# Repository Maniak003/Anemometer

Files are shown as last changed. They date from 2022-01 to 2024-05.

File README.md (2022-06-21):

<!DOCTYPE html>
<html lang="en" data-color-mode="auto" data-light-theme="light" data-dark-theme="dark">
  <head>
    <meta charset="utf-8">
  </head>
    <body class="logged-in env-production page-responsive page-blob" style="word-wrap: break-word;">
      <p> UltraSonic Anemometer.<br><b>Temperature instability was found. I'm trying to solve a problem. </p>
      <a href="https://github.com/Maniak003/Anemometer/wiki" rel="nofollow">
        Wind watcher
      </a>
      <a href="https://github.com/Maniak003/Anemometer/wiki/ZabbixSetting" rel="nofollow">
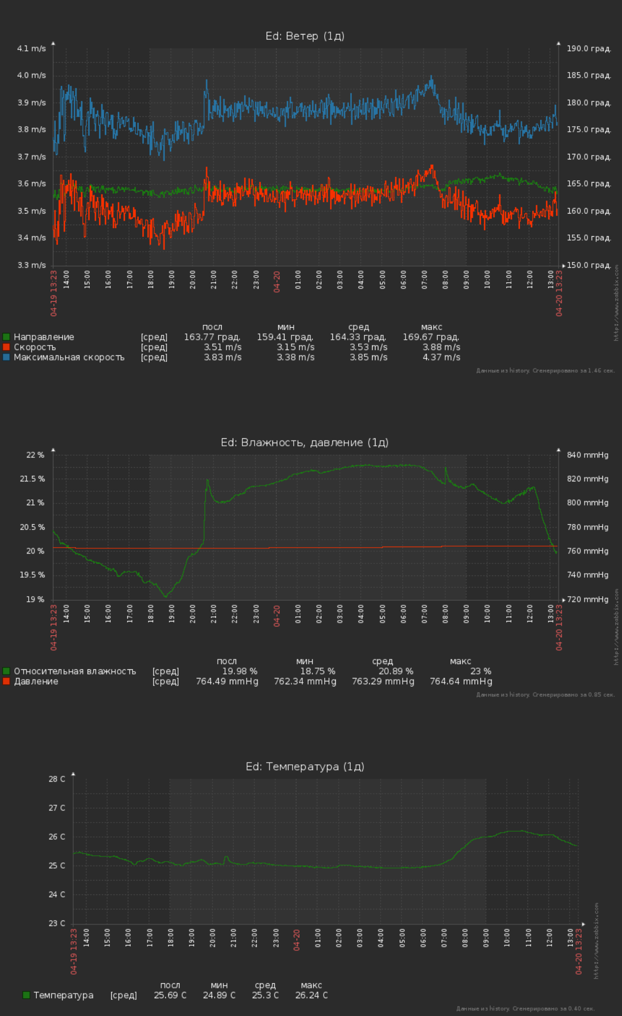
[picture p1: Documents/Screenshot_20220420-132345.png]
        
      </a>
      <a href="https://github.com/Maniak003/Anemometer/wiki/Description" rel="nofollow">
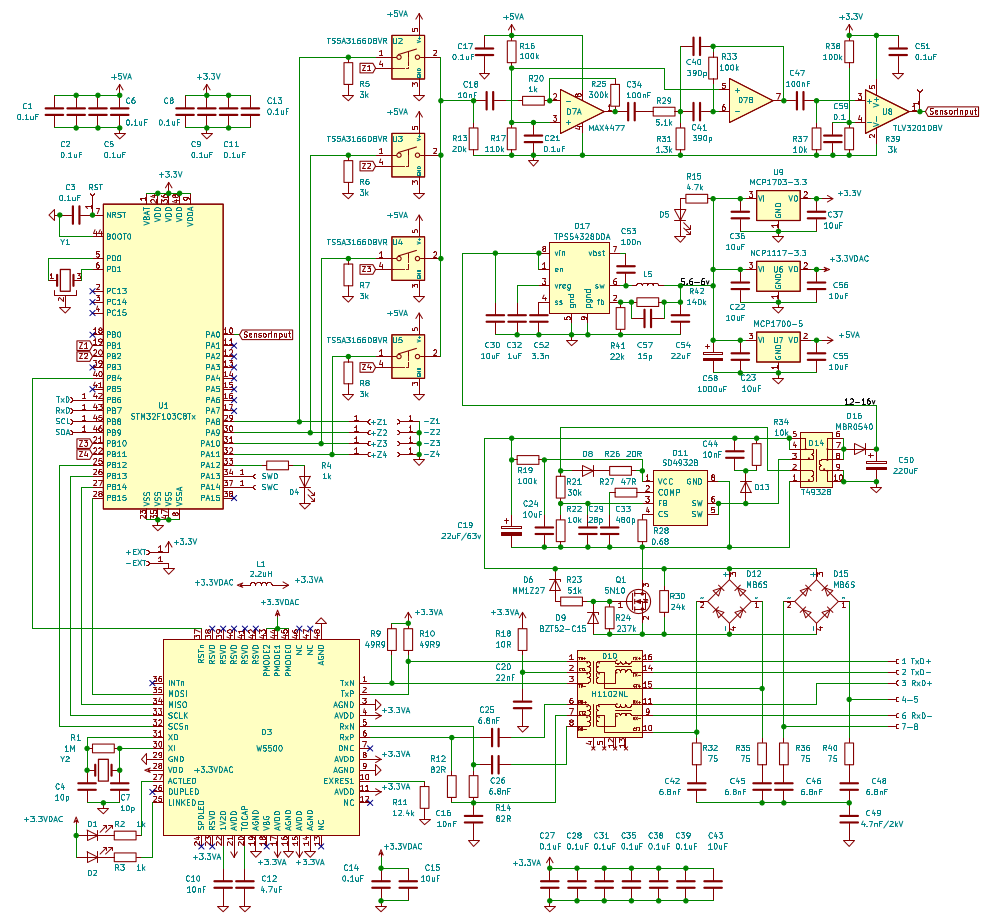
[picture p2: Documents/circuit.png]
        
      </a>
      <a href="https://github.com/Maniak003/Anemometer/wiki/Description" rel="nofollow">Description</a>
    </body>
</html>

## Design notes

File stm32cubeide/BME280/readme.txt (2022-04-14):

1. Запустим с помощью Cube MX файл в корне папки с проектом с расширением ioc
2. В Cube MX сгенерируем проект и откроем его.
3. Скомпилируем проект в Keil и проектом теперь можно пользоваться.

1. Start by using Cube MX file in the root folder with the project with the extension ioc
2. Generate the project in the Cube MX and open it.
3. Compile the project in the Keil and the project can now be used.

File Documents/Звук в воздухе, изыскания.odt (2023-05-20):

Скорость звука.

v = sqrt{ dP over {d%rho }}; v= sqrt{ %chi *{{R * T} over %mu} } (1)

χ – Показатель адиабаты. Отношение теплоемкостей при постоянном давлении и постоянном объеме.

R – Универсальная газовая постоянная.

T – Температура в градусах Кельвина.

μ – Молярная масса.

Парциальное давление насыщенного пара, эмпирическая формула, от -45ºC до 45ºC .

P_н = 1.84 * 10^11 * e^ left( - {{5330} over {T}} right ) (2)

Расчет парциального давления по относительной влажности.

P_п = { f_1 } over { 100 } * P_н (3)

Влажный воздух — смесь водяного пара и сухого воздуха. Давление влажного воздуха равно сумме парциальных давлений сухого воздуха и водяного пара. Молярная масса влажного воздуха.

%mu = r_в*%mu_в + r_п*%mu_п (4)

rв - Объемная доля сухого воздуха.

rп - Объемная доля водяного пара.

r_в = P_в over P = { (P - P_п) } over P (5); r_п = P_п over P (6)

%mu = 28.98 - 10.944 * {{ P_п } over P} (7)

Молярная масса водяного пара.

Состав воздуха.

O_2^{21%} + N_2^{ 78% } + Ar_2^{ 0.5%} + CO_2^{ 0.5% } (8)

Состав воды.

H_2^2 + O^1
(9)

Молярная масса через количество вещества.

%mu_{ cp } =( sum from{1} to{n} M_i*v_i ) / ( sum from{1} to{n} v_i ) (10)

%mu_{ cp }(воздуха) = {( 0.21 * 32 + 0.78 * 28 + 0.005 * 40 + 0.005 * 44 )} over { 0.21 + 0.78 + 0.005 + 0.005 } = 28.98 г over моль (11)

%mu_{ cp }(воды) = {( 2 * 1.0 + 1 * 16)} over 1000 = 18 г over моль (12)

Проверка влияния влажности на скорость звука.

Пусть температура постоянная и равна 20º C или 293K. Рассчитаем скорость для сухого воздуха.

v = sqrt{ 1.4 * 8.31446262 * 293 over 0.02898 } = 343,05656 m over s

Теперь рассчитаем скорость звука при той же температуре, но 100% влажности. Сначала получим молярную массу влажного воздуха, для этого нам требуется парциальное давление.

P_н = 1.84*10^11 * e^{ left(-{5330 over 293} right )} = 2314,792465 Па

Рассчитывать будем для нормального атмосферного давления.

%mu = 28.98 - 10.944 * {2314.792465 over 101325} = 28,72998 г over моль

Наконец получим скорость.

v = sqrt{ 1.4 * 8.31446262 * 293 over 0.02872998 } = 344,546 m over s

При изменении влажность на 100%, получаем изменение скорости на 1,489 m/s.

В табличку можно вносить значения: температуры, влажности, давления, времени задержки. Будут рассчитаны: скорость и дистанция.

V = sqrt(1,4*8,31446262*(temperature+273) / (0,02898 - 184000000000 * exp(-5330/(temperature+273)) * 10,944 / (pressure*101325/760) / 100000 * humidity) )

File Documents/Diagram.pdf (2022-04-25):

Z1 | Z2
Z4 | Z3
Z41 | Z14

Z12

Z21

Z32 Z23

Z34

Z43

X = (Z12 - Z21 - DX1.f + Z43 - Z34 - DX2.f) / 2; Y = (Z23 - Z32 - DY2.f + Z14 - Z41 - DY1.f) / 2;

Ю | С

З

В

Zmn

Znm

Pulse | C

# Echo

0º

90º

180º

270º

α = acos( Vx / V)

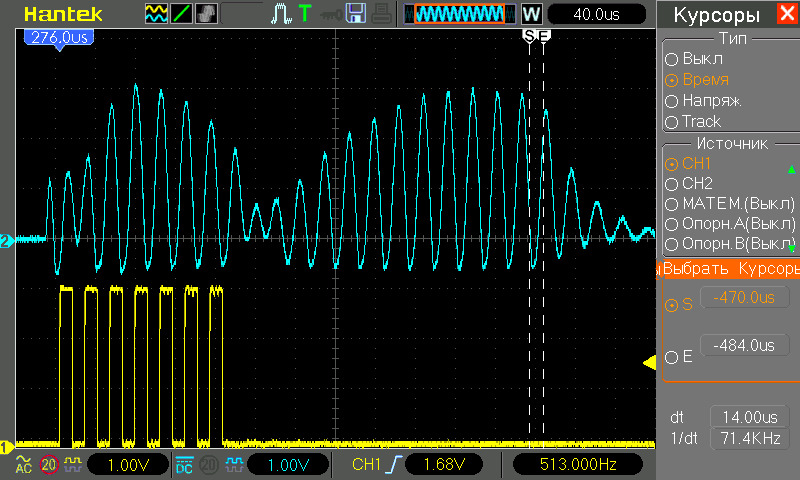
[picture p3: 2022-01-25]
Documents/pic_126_5.jpg

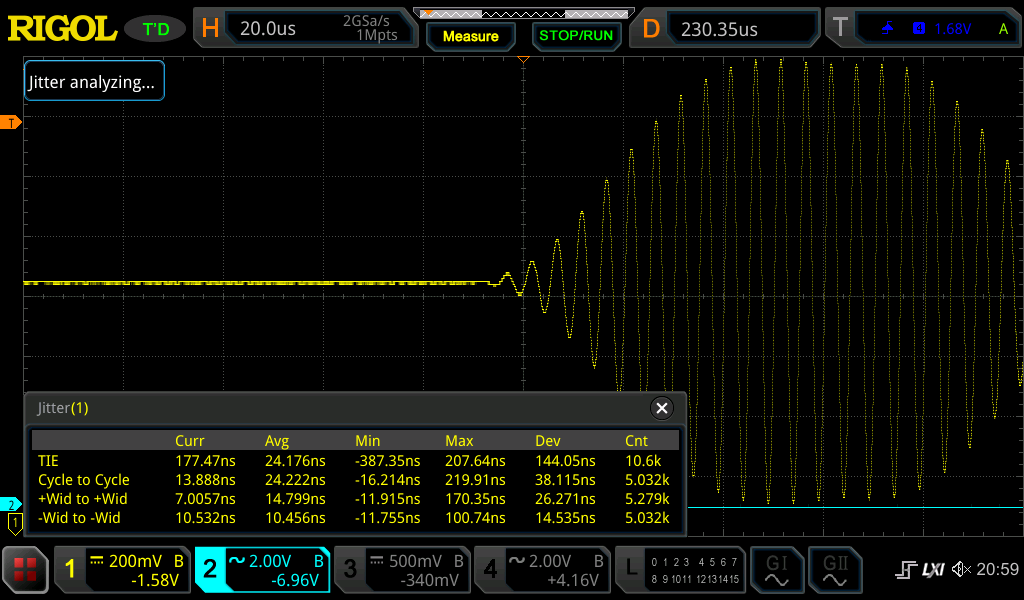
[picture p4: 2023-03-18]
Documents/Jitter-Crystall_200khz.png

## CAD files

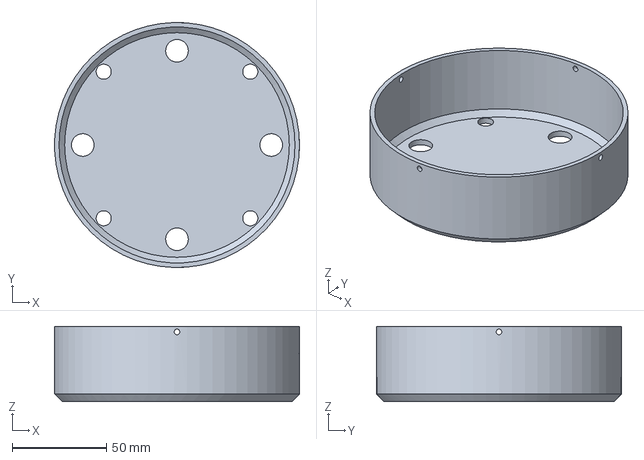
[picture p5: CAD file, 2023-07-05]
FreeCAD/base-200.FCStd
130.0 x 130.0 x 40.0 mm

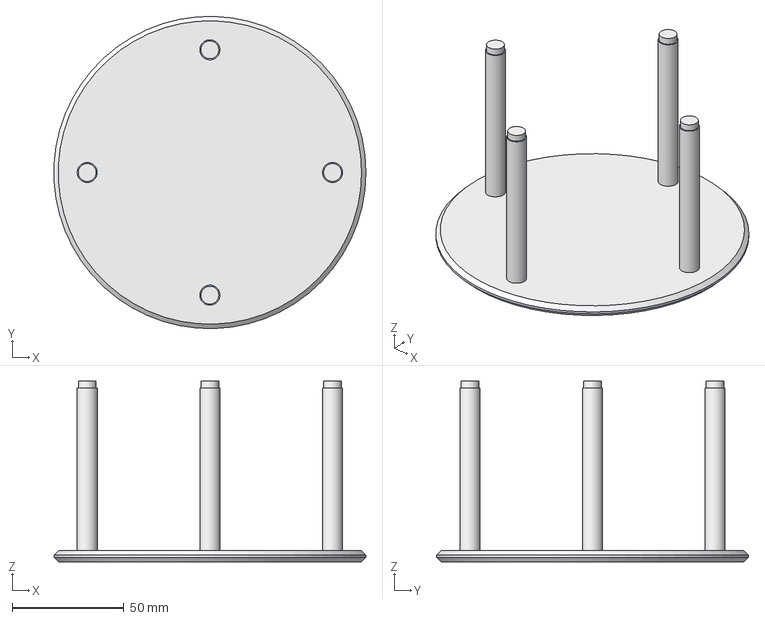
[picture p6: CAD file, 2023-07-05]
FreeCAD/cover-200.FCStd
139.9 x 139.9 x 81.0 mm

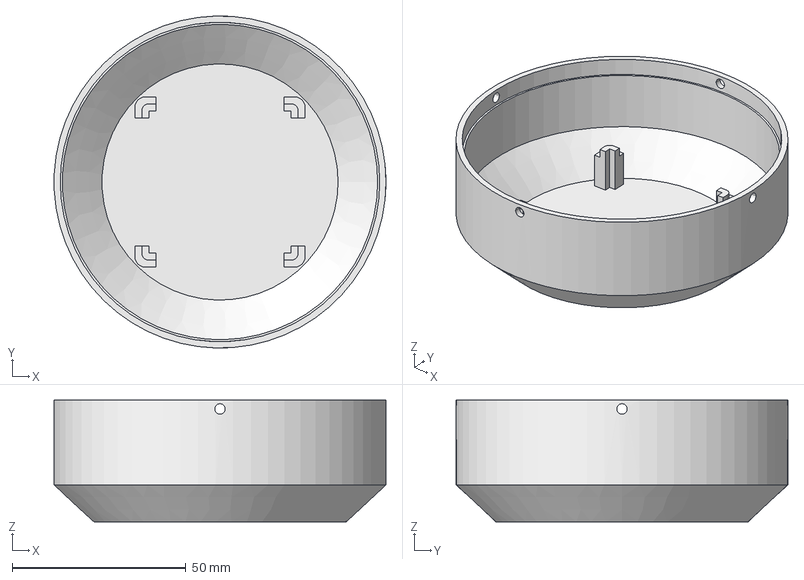
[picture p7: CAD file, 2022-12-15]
FreeCAD/cover-5.FCStd
95.6 x 95.6 x 35.0 mm

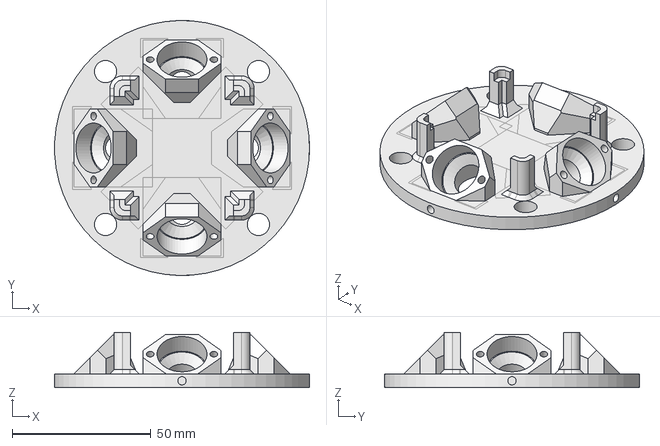
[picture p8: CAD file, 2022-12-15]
FreeCAD/base-5.FCStd
92.0 x 92.0 x 20.0 mm

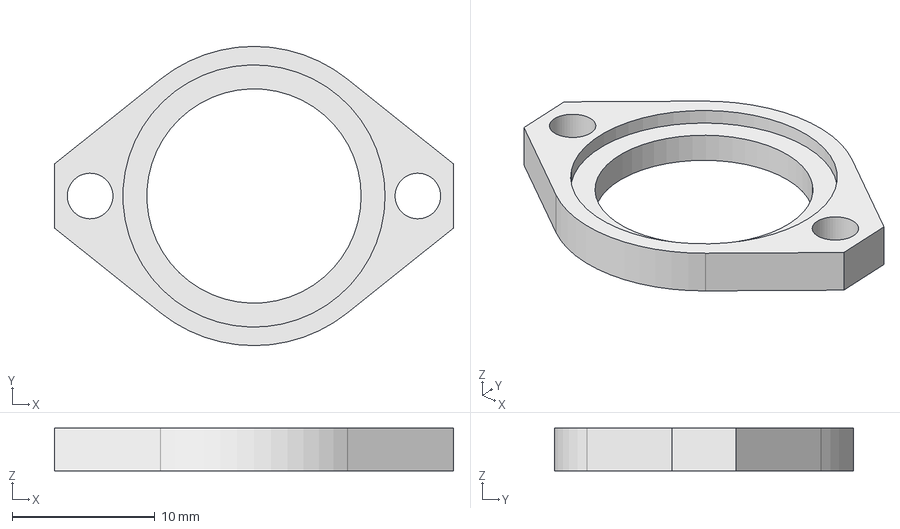
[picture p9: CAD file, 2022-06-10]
FreeCAD/support.FCStd
28.0 x 21.0 x 3.00 mm

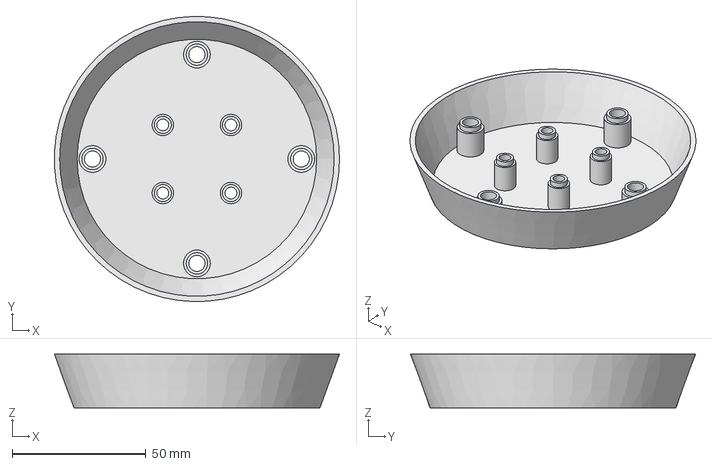
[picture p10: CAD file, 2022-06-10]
FreeCAD/shield-5-1.FCStd
106.5 x 106.5 x 20.0 mm

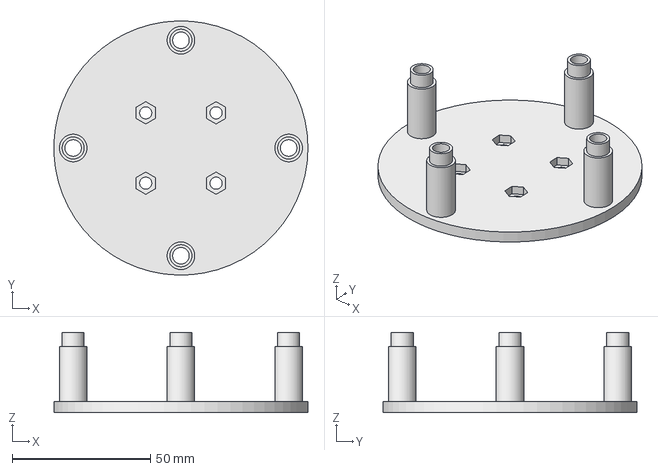
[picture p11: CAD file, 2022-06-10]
FreeCAD/holder-5.fcstd
91.9 x 92.0 x 29.0 mm

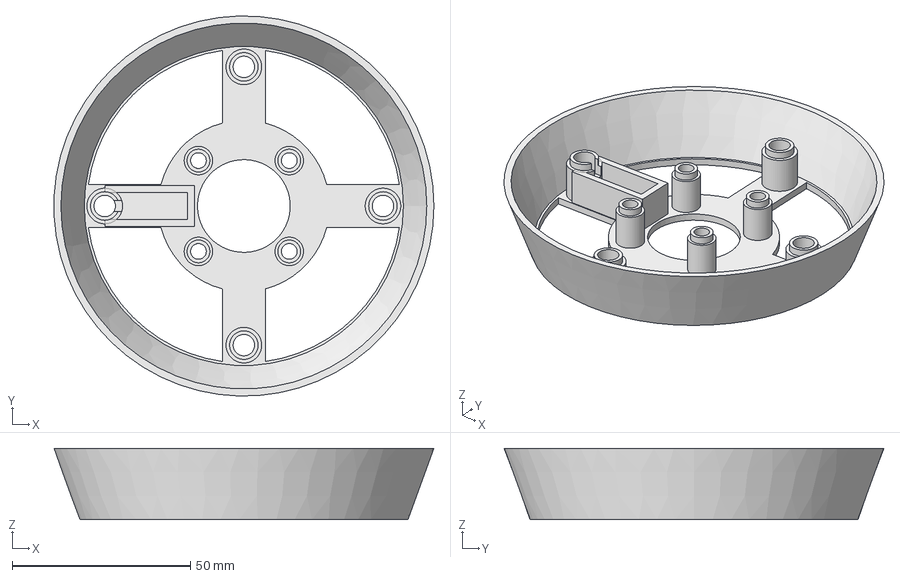
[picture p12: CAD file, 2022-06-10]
FreeCAD/shield-5-2.FCStd
106.5 x 106.5 x 20.0 mm

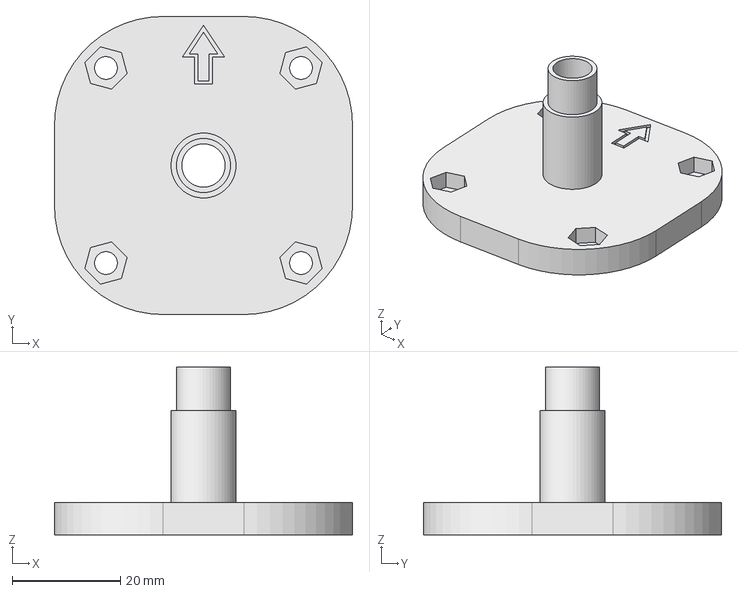
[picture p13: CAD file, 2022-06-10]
FreeCAD/holder-3.fcstd
55.0 x 55.0 x 31.0 mm

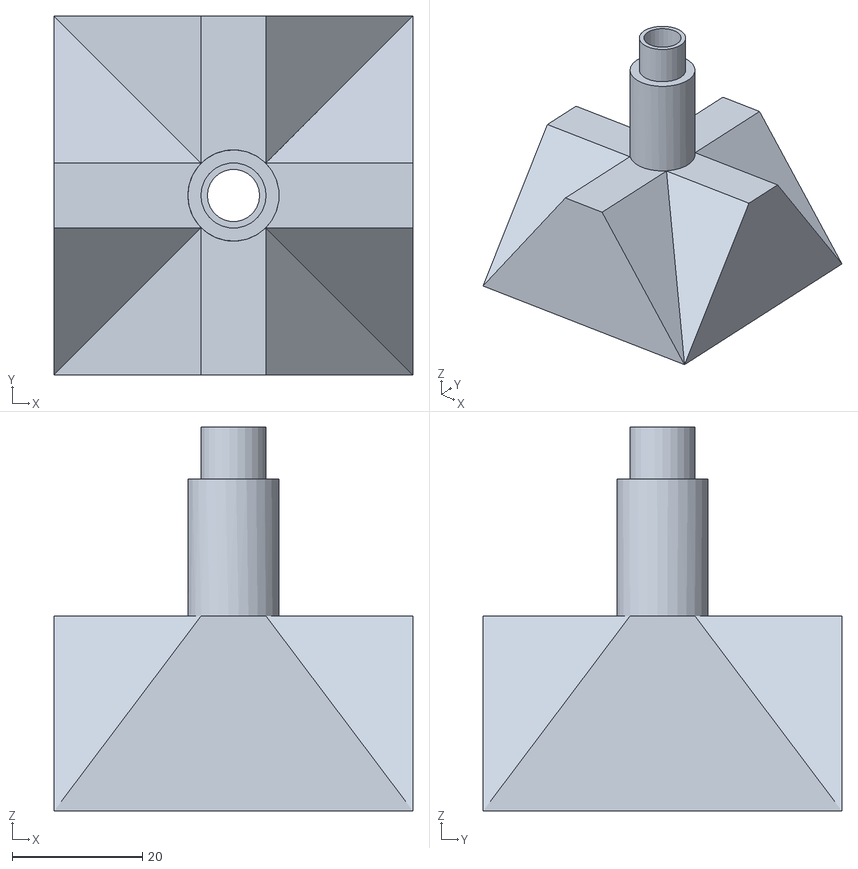
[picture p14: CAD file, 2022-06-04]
FreeCAD/holder-4.stl
55.0 x 55.0 x 58.9

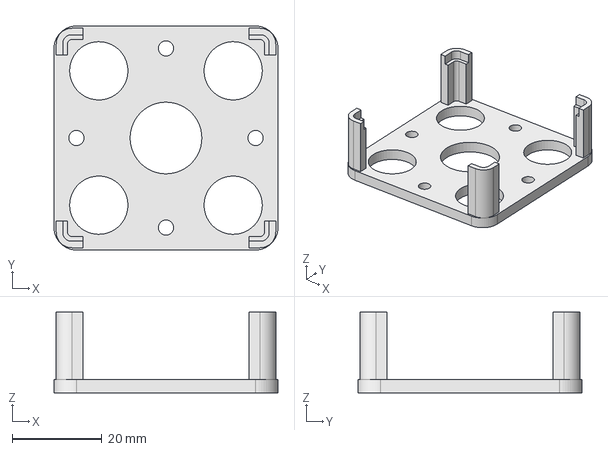
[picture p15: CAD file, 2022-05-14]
FreeCAD/plate-4.FCStd
50.0 x 50.0 x 18.0 mm

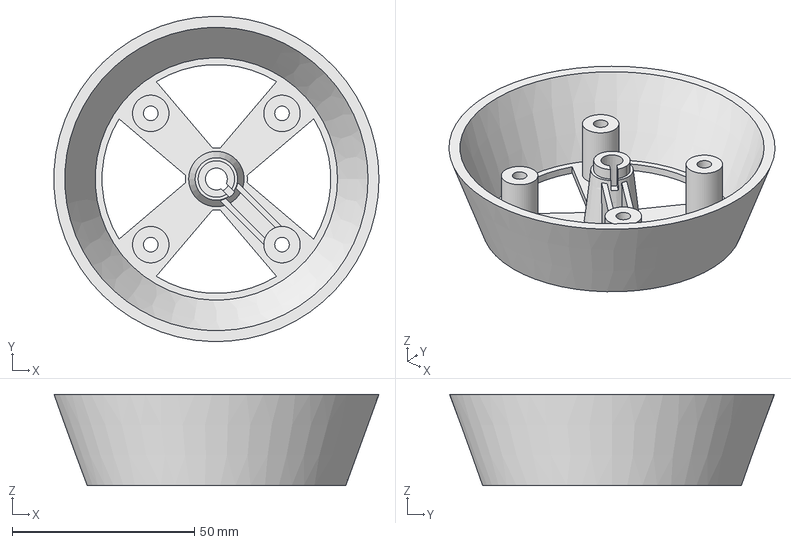
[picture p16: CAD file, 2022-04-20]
FreeCAD/shield-2.FCStd
89.1 x 89.2 x 25.0 mm

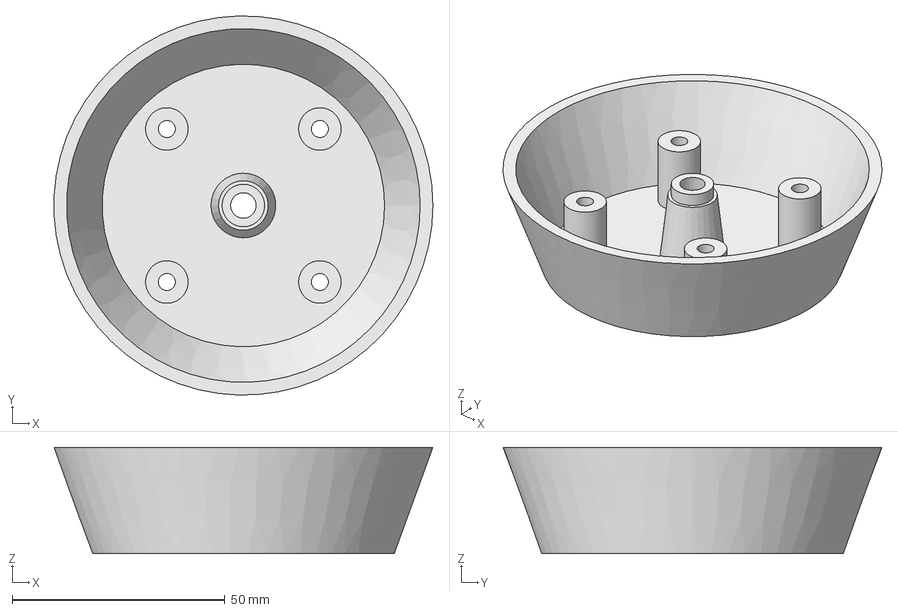
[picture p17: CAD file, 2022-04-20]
FreeCAD/shield.FCStd
89.1 x 89.2 x 25.0 mm

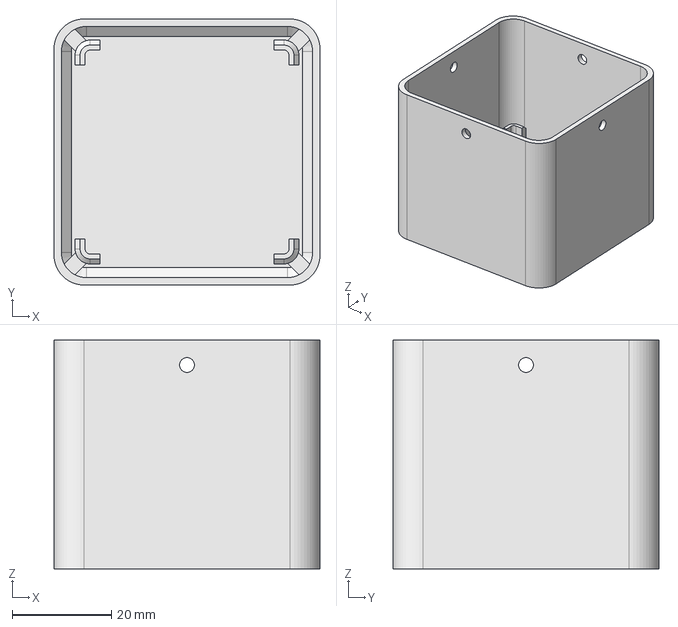
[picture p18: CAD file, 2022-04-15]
FreeCAD/cover-4.fcstd
53.5 x 53.5 x 46.0 mm

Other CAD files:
FreeCAD/base-4.FCStd
FreeCAD/base-3.FCStd
FreeCAD/base-4.stl
FreeCAD/base-5.stl
FreeCAD/cover-4.stl
FreeCAD/cover-5.stl
FreeCAD/holder-5.stl
FreeCAD/plate-4.stl
FreeCAD/shield-2.stl
FreeCAD/shield-5-1.stl
FreeCAD/shield-5-2.stl
FreeCAD/shield.stl

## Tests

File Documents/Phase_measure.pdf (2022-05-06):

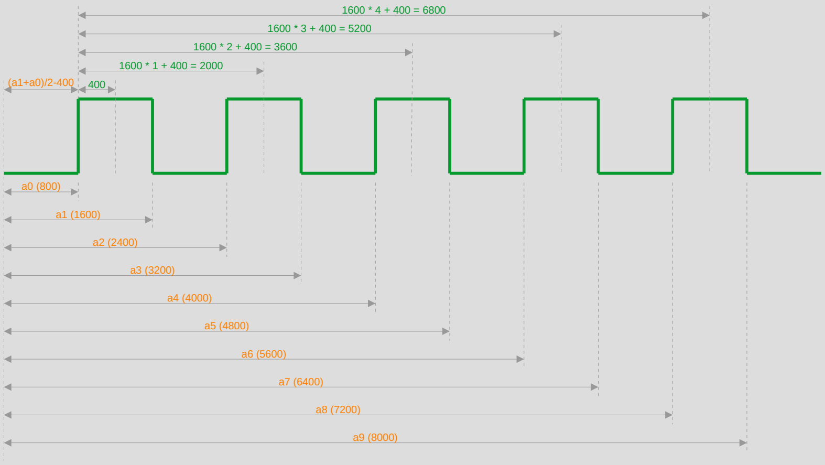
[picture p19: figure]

N=5 ;(

a1+a0
2

−400+

a3+a2
2

−2000+

a5+a4
2

−3600+

a7+a6
2

−5200+

a9+a8
2

−6800)/5=

a0+a1+a2+a3+a4+a5+a6+a7+a8+a9 10

−3600

∑

i=0

N−1
(
a2 i+1+a2i
2

−(1600⋅i+400))

N

=

∑n=0

2 N−1
an

2 N

−

1600⋅(N−1)
2

## −400 ; N=number of pulses

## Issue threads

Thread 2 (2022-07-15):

Обратная связь

captry, 2022-07-15:
Здравствуйте, заинтересовала Ваша разработка. Не знакомы ли вы с такой работой по созданию анемометра?[https://www.researchgate.net/publication/326932047_Razrabotka_ultrazvukovogo_anemometra ](url).
captry@yandex.ru. Сергей.

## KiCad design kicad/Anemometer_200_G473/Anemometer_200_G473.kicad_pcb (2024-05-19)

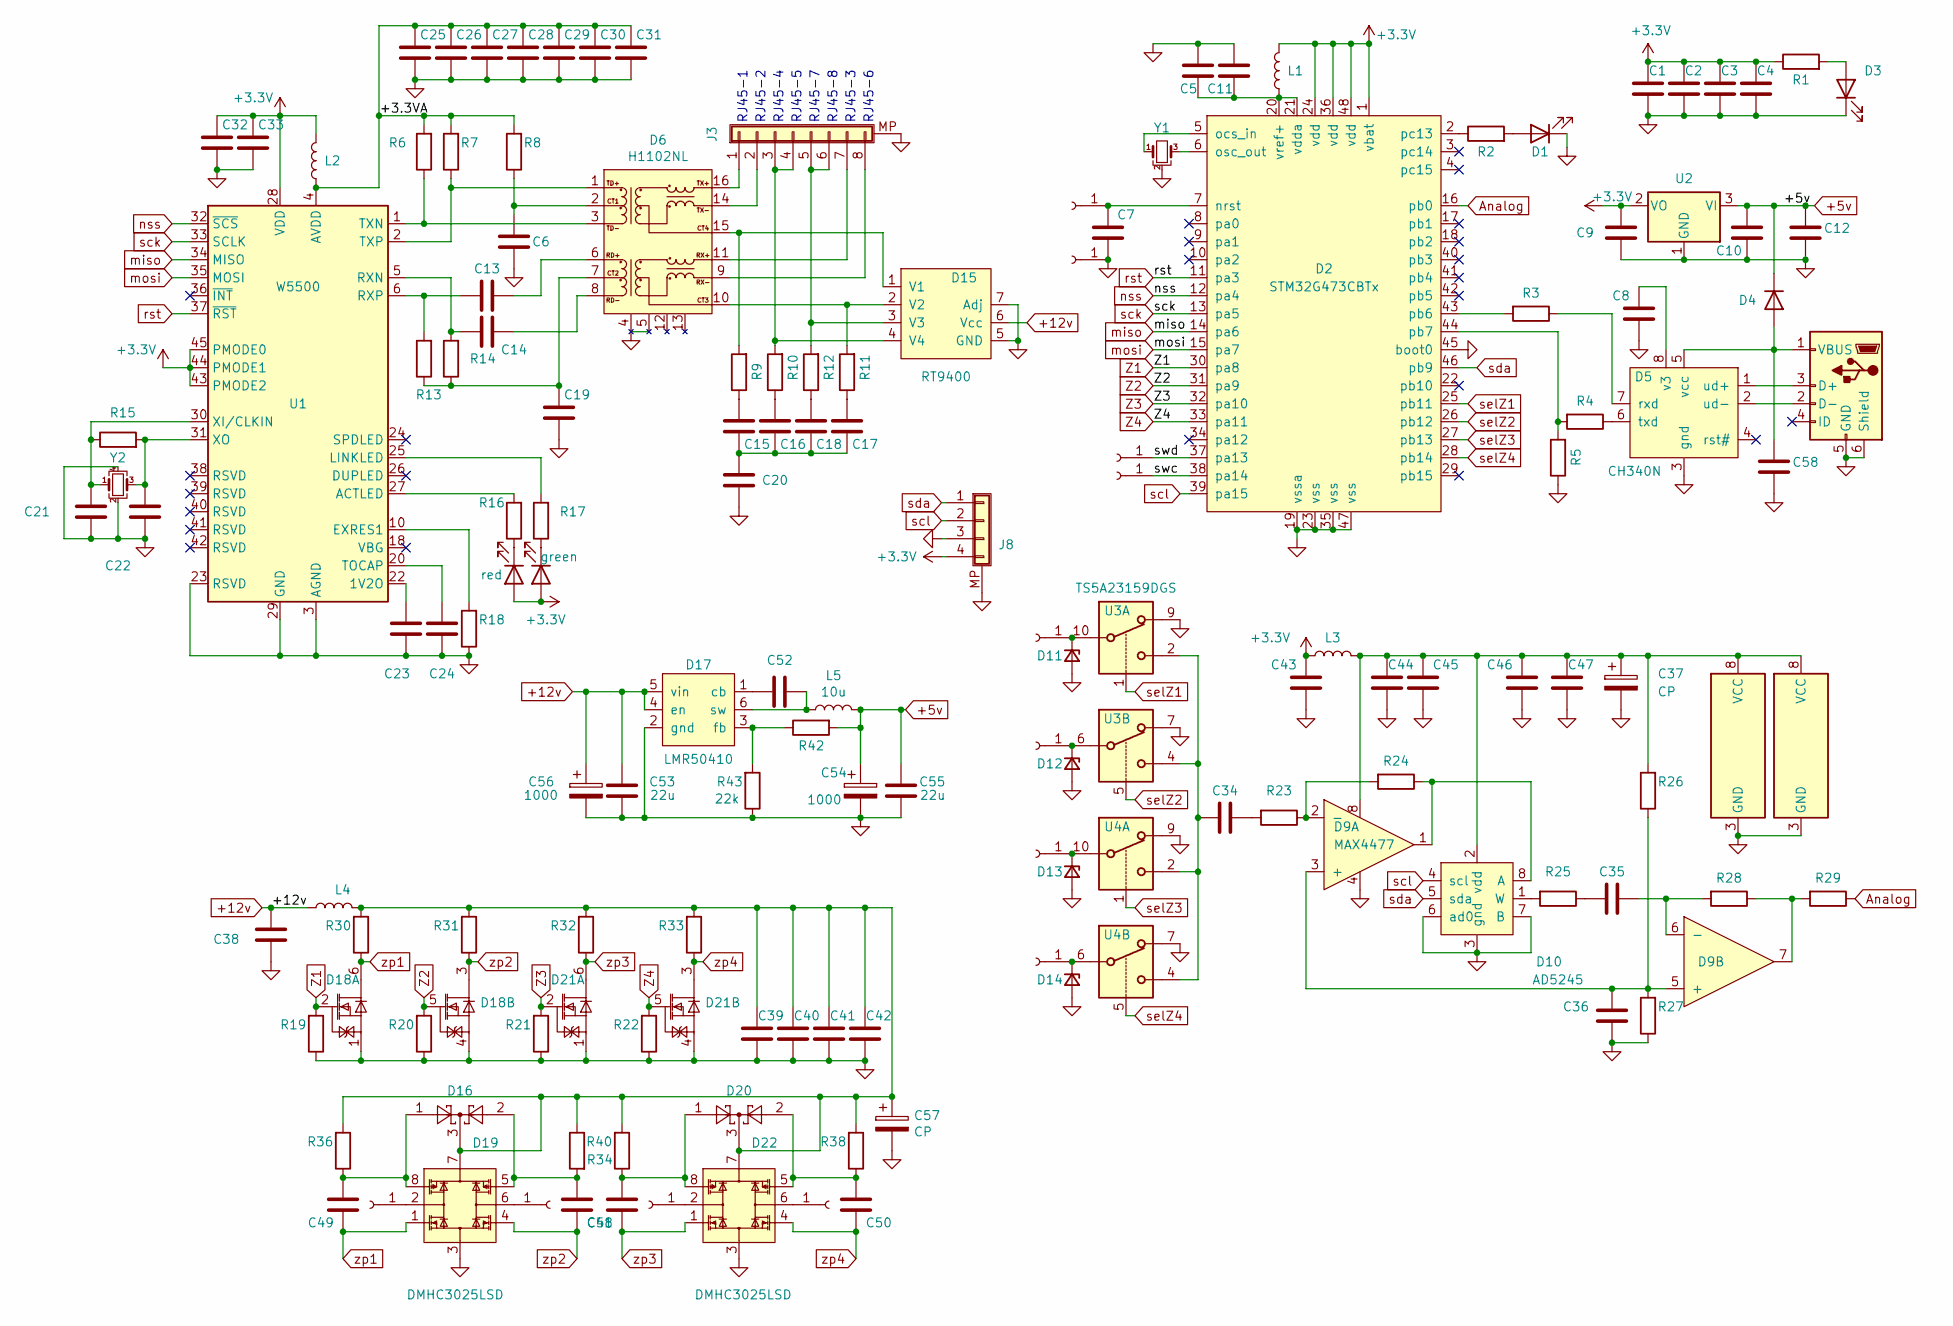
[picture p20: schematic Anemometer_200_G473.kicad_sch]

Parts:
C1, C8, C9, C38, C43, C44, C45, C46, C47: C; C_0603_1608Metric
C2, C3, C4, C5, C10, C11, C12, C39, C40, C41, C42, C58: C; C_0805_2012Metric
C6, C25, C26, C27, C28, C29, C30, C31, C32, C33: 22n; C_0402_1005Metric
C7: C; C_0402_1005Metric
C13, C14, C15, C16, C17, C18, C36: 6.8n; C_0402_1005Metric
C19, C23: 10n; C_0402_1005Metric
C20: 10n; C_1206_3216Metric
C21, C22: 10; C_0402_1005Metric
C24, C34, C35: 4.7u; C_0402_1005Metric
C37, C57: CP; CP_EIA-7343-40_Kemet-Y_Pad2.25x2.55mm_HandSolder
C48, C49, C50, C51, C52: 85n; C_0603_1608Metric
C53, C55: 22u; C_0805_2012Metric
C54, C56: 1000; CP_EIA-7343-40_Kemet-Y_Pad2.25x2.55mm_HandSolder
D1, D3: LED; LED_0603_1608Metric
D2: STM32G473CBTx; LQFP-48_7x7mm_P0.5mm
D4: D; D_MiniMELF
D5: CH340N; SOP-8_3.9x4.9mm_P1.27mm
D6: H1102NL; H1102N
D7: red; LED_0603_1608Metric
D8: green; LED_0603_1608Metric
D9: MAX4477; MSOP-8_3x3mm_P0.65mm
D10: AD5245; MSOP-8_3x3mm_P0.65mm
D11, D12, D13, D14: D_Zener_Small; D_SOD-123
D15: RT9400; TR9400
D16, D20: BAT54C; SOT-23
D17: LMR50410; SOT-23-6
D18, D21: DMN5L06DWK-7; SOT-363_SC-70-6
D19, D22: DMHC3025LSD; SO-8_5.3x6.2mm_P1.27mm
J1, J2, J4, J13, J15, J16, J17, J20, J21, J22, J23, J24: Conn_01x01_Female; conn_mini
J3: Conn_01x08_Shielded; JST_GH_BM08B-GHS-TBT_1x08-1MP_P1.25mm_Vertical
J8: Conn_01x04_Shielded; JST_SH_BM04B-SRSS-TB_1x04-1MP_P1.00mm_Vertical
J11: USB_B_Micro; USB_Micro-B_Molex_47346-0001
L1: L; L_0805_2012Metric
L2, L4: 10u; L_0805_2012Metric
L3: 47u; L_0805_2012Metric
L5: 10u; L_Bourns_SRP7028A_7.3x6.6mm
R1, R2, R3, R4, R5, R23, R24, R25, R28, R29: R; R_0603_1608Metric
R6, R7: 49.9; R_0402_1005Metric
R8: 10; R_0402_1005Metric
R9, R10, R11, R12: 75; R_0402_1005Metric
R13, R14: 82; R_0402_1005Metric
R15: 1M; R_0402_1005Metric
R16, R17: 510; R_0402_1005Metric
R18, R26, R27, R34, R36, R38, R40, R42: 12.4k; R_0402_1005Metric
R19, R20, R21, R22: 100k; R_0402_1005Metric
R30, R31, R32, R33: 100; R_0402_1005Metric
R43: 22k; R_0402_1005Metric
U1: W5500; LQFP-48_7x7mm_P0.5mm
U2: NCP1117-3.3; SOT-223-3_TabPin2
U3, U4: TS5A23159DGS; VSSOP-10_3x3mm_P0.5mm
Y1: 16; Resonator_SMD_muRata_CSTxExxV-3Pin_3.0x1.1mm
Y2: 25MHz; Crystal_SMD_SeikoEpson_FA238-4Pin_3.2x2.5mm

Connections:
+3V3: C1.1, C2.1, C3.1, C4.1, C9.1, C32.1, C33.1, C43.1, D2.1 (vbat), D2.24 (vdd), D2.36 (vdd), D2.48 (vdd), D7.2 (A), D8.2 (A), J8.4, L1.2, L2.2, L3.1, R1.1, U1.28 (VDD), U1.43 (PMODE2), U1.44 (PMODE1), U1.45 (PMODE0), U2.2 (VO)
+5v: C10.1, C12.1, C54.1, C55.2, D4.1 (K), L5.2, R42.2, U2.3 (VI)
+12v: C38.1, C53.2, C56.1, D15.6 (Vcc), D17.4 (en), D17.5 (vin), L4.1
/+3.3VA: C25.1, C26.1, C27.1, C28.1, C29.1, C30.1, C31.1, L2.1, R6.2, R7.2, R8.2, U1.4 (AVDD), U1.8 (AVDD), U1.11 (AVDD), U1.15 (AVDD), U1.17 (AVDD), U1.21 (AVDD)
/swc: D2.38 (pa14), J21.1
/swd: D2.37 (pa13), J20.1
Analog: D2.16 (pb0), R29.1
GND: C1.2, C2.2, C3.2, C4.2, C5.2, C6.2, C7.2, C8.2, C9.2, C10.2, C11.2, C12.2, C19.2, C20.2, C21.2, C22.2, C23.2, C24.2, C25.2, C26.2, C27.2, C28.2, C29.2, C30.2, C31.2, C32.2, C33.2, C36.1, C37.2, C38.2, C39.2, C40.2, C41.2, C42.2, C43.2, C44.2, C45.2, C46.2, C47.2, C53.1, C54.2, C55.1, C56.2, C57.2, C58.2, D1.1 (K), D2.19 (vssa), D2.23 (vss), D2.35 (vss), D2.45 (boot0), D2.47 (vss), D3.1 (K), D5.3 (gnd), D6.4, D6.5, D9.4, D10.3 (gnd), D10.6 (ad0), D10.7 (B), D11.2 (A), D12.2 (A), D13.2 (A), D14.2 (A), D15.5 (GND), D15.7 (Adj), D17.2 (gnd), D18.1, D18.4, D19.3, D21.1, D21.4, D22.3, J3.MP (Shield), J4.1, J8.3, J8.MP (Shield), J11.5 (GND), J11.6 (Shield), R5.1, R18.1, R19.1, R20.1, R21.1, R22.1, R27.1, R43.1, U1.3 (AGND), U1.9 (AGND), U1.14 (AGND), U1.16 (AGND), U1.19 (AGND), U1.23 (RSVD), U1.29 (GND), U1.48 (AGND), U2.1 (GND), U3.3 (GND), U3.7, U3.9, U4.3 (GND), U4.7, U4.9, Y1.2, Y2.2, Y2.4
unnamed: C6.1, D6.2, R8.1
unnamed: C7.1, D2.7 (nrst), J1.1
unnamed: C8.1, D5.8 (v3)
unnamed: C5.1, C11.1, D2.20 (vref+), D2.21 (vdda), L1.1
unnamed: C13.1, D6.6
unnamed: C13.2, R13.2, U1.6 (RXP)
unnamed: C14.1, D6.8
unnamed: C14.2, R14.2, U1.5 (RXN)
unnamed: C15.2, R9.1
unnamed: C16.2, R10.1
unnamed: C18.2, R12.1
unnamed: C19.1, D6.7, R13.1, R14.1
unnamed: C15.1, C16.1, C17.1, C18.1, C20.1
unnamed: C21.1, R15.1, U1.30 (XI/CLKIN), Y2.1
unnamed: C22.1, R15.2, U1.31 (XO), Y2.3
unnamed: C23.1, U1.22 (1V2O)
unnamed: C24.1, U1.20 (TOCAP)
unnamed: C34.1, R23.2
unnamed: C34.2, U3.2, U3.4, U4.2, U4.4
unnamed: C35.1, D9.6 (-), R28.2
unnamed: C35.2, R25.1
unnamed: C36.2, D9.3 (+), D9.5 (+), R26.1, R27.2
unnamed: C37.1, C44.1, C45.1, C46.1, C47.1, D9.8, D10.2 (vdd), L3.2, R26.2, U3.8 (VCC), U4.8 (VCC)
unnamed: C39.1, C40.1, C41.1, C42.1, C57.1, D16.3, D19.7, D20.3, D22.7, L4.2, R30.2, R31.2, R32.2, R33.2, R34.1, R36.2, R38.2, R40.2
unnamed: C48.1, D16.2, D19.5, R34.2
unnamed: C49.1, D16.1, D19.8, R36.1
unnamed: C50.1, D20.2, D22.5, R38.1
unnamed: C51.1, D20.1, D22.8, R40.1
unnamed: C52.1, D17.6 (sw), L5.1
unnamed: C52.2, D17.1 (cb)
unnamed: D1.2 (A), R2.2
unnamed: D2.2 (pc13), R2.1
unnamed: D2.5 (ocs_in), Y1.1
unnamed: D2.6 (osc_out), Y1.3
unnamed: D2.43 (pb6), R3.2
unnamed: D2.44 (pb7), R4.2, R5.2
unnamed: D3.2 (A), R1.2
unnamed: C58.1, D4.2 (A), D5.5 (vcc), J11.1 (VBUS)
unnamed: D5.1 (ud+), J11.3 (D+)
unnamed: D5.2 (ud-), J11.2 (D-)
unnamed: D5.6 (txd), R4.1
unnamed: D5.7 (rxd), R3.1
unnamed: D6.9, J3.8
unnamed: D6.11, J3.7
unnamed: D6.14, J3.2
unnamed: D6.16, J3.1
unnamed: D9.2 (-), R23.1, R24.2
unnamed: D9.7, R28.1, R29.2
unnamed: D10.1 (W), R25.2
unnamed: D9.1, D10.8 (A), R24.1
unnamed: D11.1 (K), J17.1, U3.10
unnamed: D12.1 (K), J22.1, U3.6
unnamed: D13.1 (K), J23.1, U4.10
unnamed: D14.1 (K), J24.1, U4.6
unnamed: D6.15, D15.1 (V1), R9.2
unnamed: D6.10, D15.2 (V2), R11.2
unnamed: D15.3 (V3), J3.5, J3.6, R12.2
unnamed: D15.4 (V4), J3.3, J3.4, R10.2
unnamed: D17.3 (fb), R42.1, R43.2
unnamed: D19.6, J2.1
unnamed: D22.2, J13.1
unnamed: D19.2, J15.1
unnamed: D22.6, J16.1
unnamed: D6.3, R6.1, U1.1 (TXN)
unnamed: D6.1, R7.1, U1.2 (TXP)
unnamed: C17.2, R11.1
unnamed: D7.1 (K), R16.1
unnamed: D8.1 (K), R17.1
unnamed: R18.2, U1.10 (EXRES1)
unnamed: R17.2, U1.25 (LINKLED)
unnamed: R16.2, U1.27 (ACTLED)
Z1: D2.30 (pa8), D18.2, R19.2
Z2: D2.31 (pa9), D18.5, R20.2
Z3: D2.32 (pa10), D21.2, R21.2
Z4: D2.33 (pa11), D21.5, R22.2
miso: D2.14 (pa6), U1.34 (MISO)
mosi: D2.15 (pa7), U1.35 (MOSI)
nss: D2.12 (pa4), U1.32 (~SCS)
rst: D2.11 (pa3), U1.37 (~RST)
sck: D2.13 (pa5), U1.33 (SCLK)
scl: D2.39 (pa15), D10.4 (scl), J8.2
sda: D2.46 (pb9), D10.5 (sda), J8.1
selZ1: D2.25 (pb11), U3.1
selZ2: D2.26 (pb12), U3.5
selZ3: D2.27 (pb13), U4.1
selZ4: D2.28 (pb14), U4.5
zp1: C49.2, D18.6, D19.1, R30.1
zp2: C48.2, D18.3, D19.4, R31.1
zp3: C51.2, D21.6, D22.1, R32.1
zp4: C50.2, D21.3, D22.4, R33.1

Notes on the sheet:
RJ45-1
RJ45-3
RJ45-2
RJ45-6
RJ45-8
RJ45-5
RJ45-4
RJ45-7

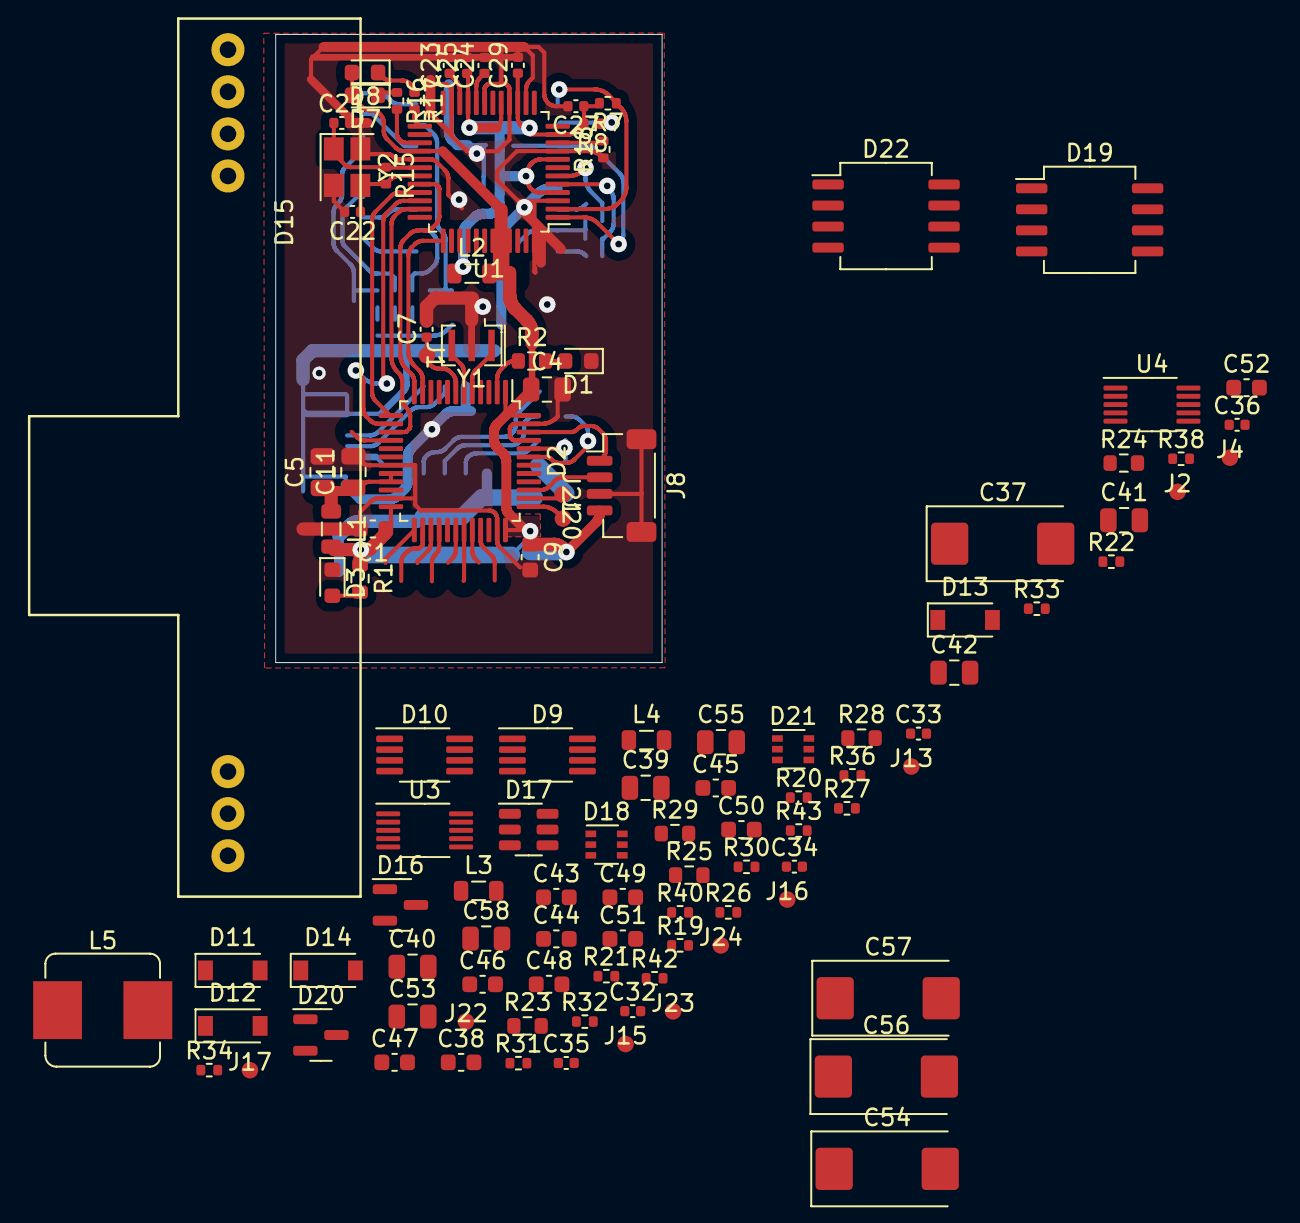
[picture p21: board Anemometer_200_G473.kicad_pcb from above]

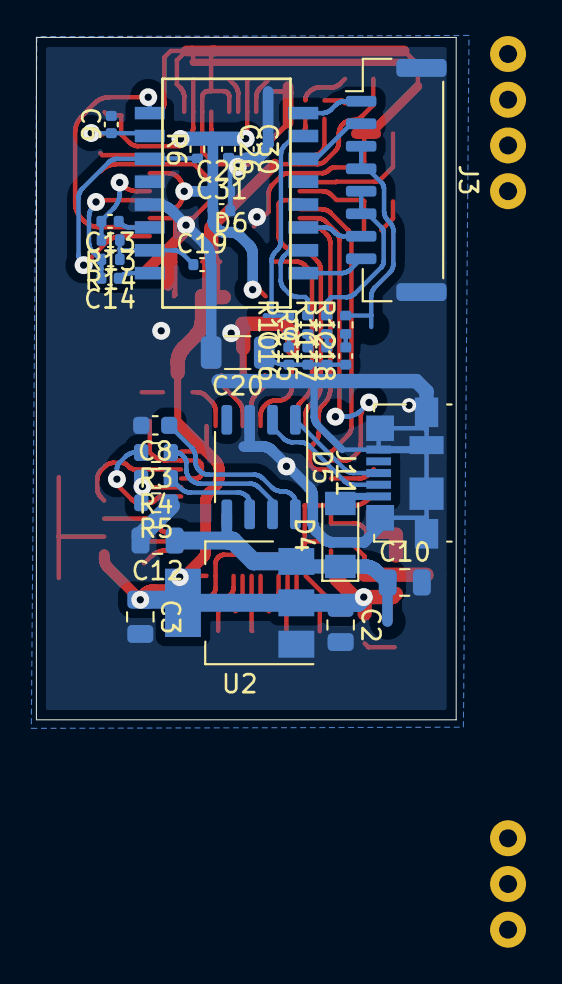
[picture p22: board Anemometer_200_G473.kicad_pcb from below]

Board: 2 copper layers, 23.3 x 37.9 mm, 145 parts (34 on the bottom side), 98 nets.

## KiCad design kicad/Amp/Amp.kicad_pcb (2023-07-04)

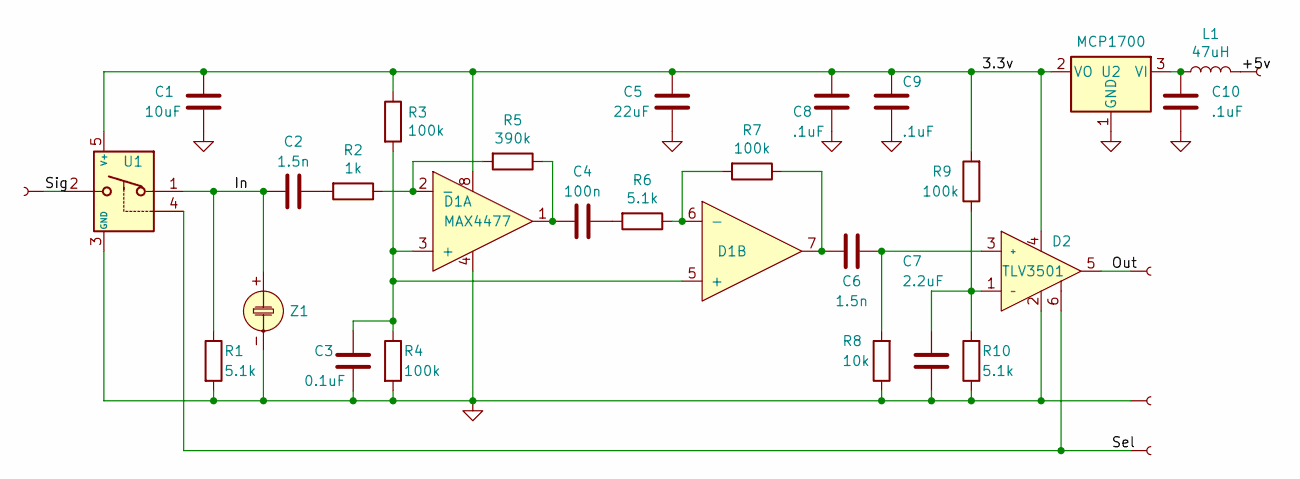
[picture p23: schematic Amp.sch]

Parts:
C1: 10uF; C_0603_1608Metric
C2, C6: 1.5n; C_0402_1005Metric
C3: 0.1uF; C_0402_1005Metric
C4: 100n; C_0402_1005Metric
C5: 22uF; C_0805_2012Metric
C7: 2.2uF; C_0402_1005Metric
C8, C9, C10: .1uF; C_0603_1608Metric
D1: MAX4477; MSOP-8_3x3mm_P0.65mm
D2: TLV3501; SOT-23-6
J1, J2, J3, J4, J5: Conn; SMD-CONN
L1: 47uH; L_0805_2012Metric
R1, R6, R10: 5.1k; R_0402_1005Metric
R2: 1k; R_0402_1005Metric
R3, R4, R7, R9: 100k; R_0402_1005Metric
R5: 390k; R_0402_1005Metric
R8: 10k; R_0402_1005Metric
U1: TS5A3166DBVR; SOT-23-5
U2: MCP1700; SOT-23
Z1: MCUSD18A40B12RS

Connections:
/3.3v: C1.1, C5.1, C8.1, C9.1, D1.8, D2.4, R3.1, R9.2, U1.5 (V+), U2.2 (VO)
/+5v: J5.1, L1.2
/In: C2.2, R1.1, U1.1, Z1.+
/Out: D2.5, J2.1
/Sel: D2.6, J4.1, U1.4
/Sig: J1.1, U1.2
GND: C1.2, C3.2, C5.2, C7.2, C8.2, C9.2, C10.2, D1.4, D2.2, J3.1, R1.2, R4.2, R8.1, R10.1, U1.3 (GND), U2.1 (GND), Z1.-
unnamed: C2.1, R2.2
unnamed: C3.1, D1.3 (+), D1.5 (+), R3.2, R4.1
unnamed: C4.1, R6.2
unnamed: C4.2, D1.1, R5.1
unnamed: C6.1, D2.3 (+), R8.2
unnamed: C6.2, D1.7, R7.1
unnamed: C7.1, D2.1 (-), R9.1, R10.2
unnamed: C10.1, L1.1, U2.3 (VI)
unnamed: D1.2 (-), R2.1, R5.2
unnamed: D1.6 (-), R6.1, R7.2

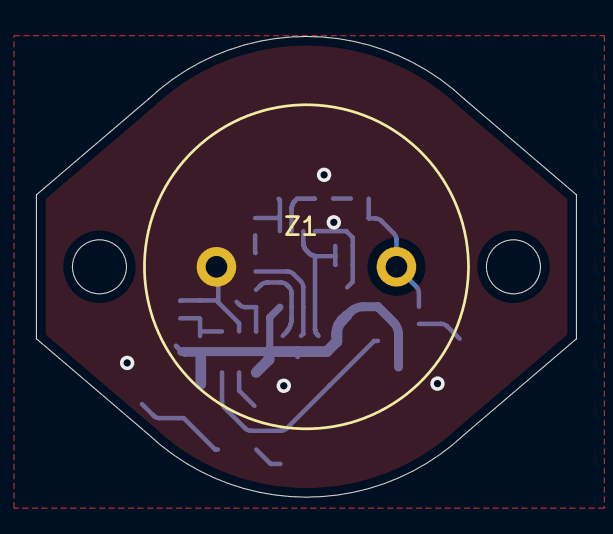
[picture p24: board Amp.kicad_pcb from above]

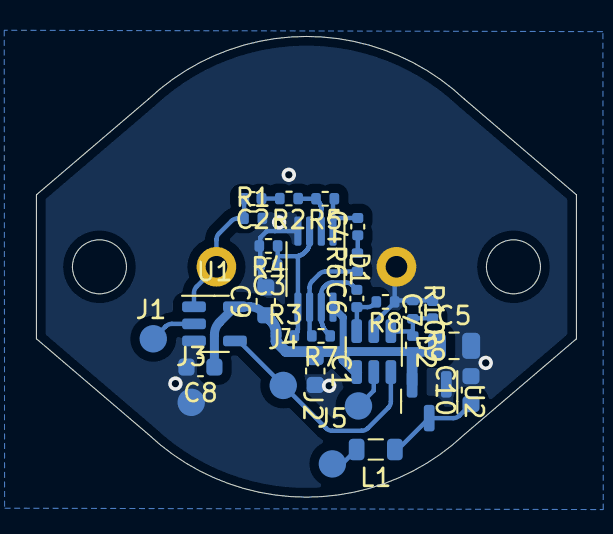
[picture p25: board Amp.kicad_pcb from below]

Board: 2 copper layers, 30.0 x 25.6 mm, 31 parts (30 on the bottom side), 17 nets.

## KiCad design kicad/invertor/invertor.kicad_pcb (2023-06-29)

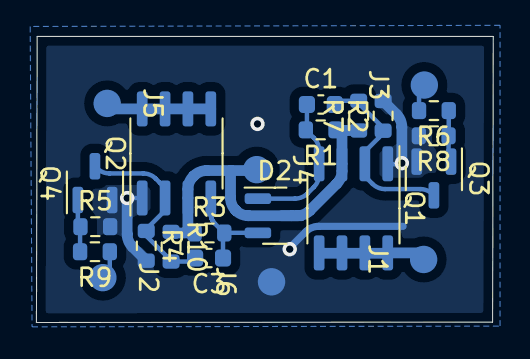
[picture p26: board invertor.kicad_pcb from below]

Board: 2 copper layers, 25.4 x 15.9 mm, 23 parts (23 on the bottom side), 12 nets.

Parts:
C1, C3: 82nF; C_0603_1608Metric
D2: BAT54C; SOT-23
J1, J2, J3, J4, J5, J6: Conn; SMD-CONN
Q1, Q2: IRF7343PBF; SOIC-8_3.9x4.9mm_P1.27mm
Q3, Q4: IRLML6344; SOT-23
R1, R2, R3, R4, R5, R8: 100k; R_0603_1608Metric
R6, R9: 10; R_0603_1608Metric
R7, R10: 100; R_0603_1608Metric

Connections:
/+12v: D2.3, J4.1, Q1.3 (1), Q2.3 (1), R1.1, R3.1, R7.1, R10.1
/Z1: J2.1, R9.1
/Z2: J3.1, R6.2
GND: J6.1, Q1.1 (S), Q2.1 (S), Q3.2 (S), Q4.2 (S), R2.2, R4.2, R5.2, R8.2
unnamed: C1.1, D2.1, Q1.4 (G), R1.2
unnamed: C1.2, Q1.2 (G), Q3.3 (D), R2.1, R7.2
unnamed: C3.1, D2.2, Q2.4 (G), R3.2
unnamed: C3.2, Q2.2 (G), Q4.3 (D), R4.1, R10.2
unnamed: J1.1, Q1.5 (D), Q1.6 (D), Q1.7 (D), Q1.8 (D)
unnamed: J5.1, Q2.5 (D), Q2.6 (D), Q2.7 (D), Q2.8 (D)
unnamed: Q3.1 (G), R6.1, R8.1
unnamed: Q4.1 (G), R5.1, R9.2

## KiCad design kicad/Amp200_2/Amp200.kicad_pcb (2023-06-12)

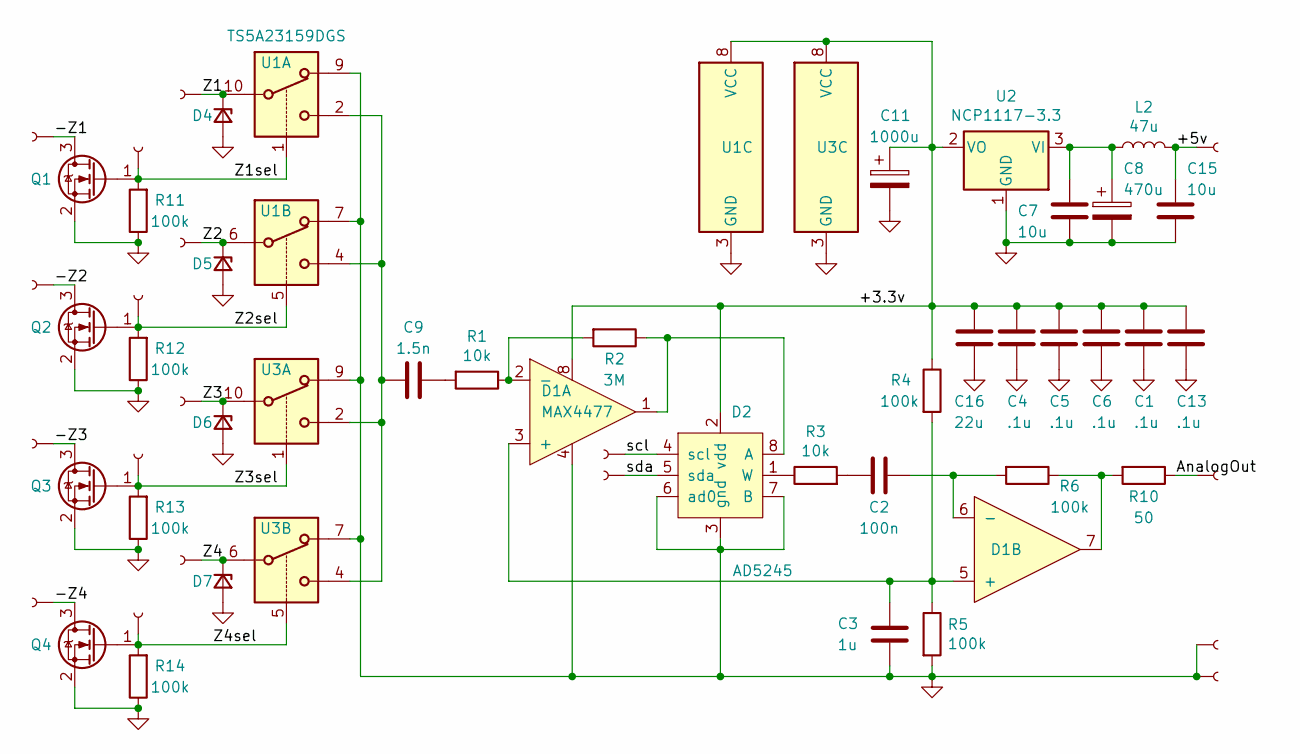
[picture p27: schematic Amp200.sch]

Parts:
C1, C4, C5, C6, C13: .1u; C_0805_2012Metric
C2: 100n; C_0603_1608Metric
C3: 1u; C_0603_1608Metric
C7, C15: 10u; C_0805_2012Metric
C8: 470u; CP_EIA-6032-28_Kemet-C
C9: 1.5n; C_0603_1608Metric
C11: 1000u; CP_EIA-6032-28_Kemet-C
C16: 22u; C_0805_2012Metric
D1: MAX4477; MSOP-8_3x3mm_P0.65mm
D2: AD5245; SOT-23-8
D4, D5, D6, D7: BZ55C2V7; D_MiniMELF
J1, J2, J3, J4, J5, J7, J8, J9, J10, J11, J12, J13, J14, J15, J16, J17, J18, J19: Conn; SMD-CONN
L2: 47u; L_0805_2012Metric
Q1, Q2, Q3, Q4: Q_NMOS_GSD; SOT-23
R1, R3: 10k; R_0603_1608Metric
R2: 3M; R_0603_1608Metric
R4, R5, R6, R11, R12, R13, R14: 100k; R_0603_1608Metric
R10: 50; R_0603_1608Metric
U1, U3: TS5A23159DGS; VSSOP-10_3x3mm_P0.5mm
U2: NCP1117-3.3; SOT-223-3_TabPin2

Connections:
/+3.3v: C1.1, C4.1, C5.1, C6.1, C11.1, C13.1, C16.1, D1.8, D2.2 (vdd), R4.1, U1.8 (VCC), U2.2 (VO), U3.8 (VCC)
/+5v: C15.1, J9.1, L2.2
/-Z1: J4.1, Q1.3 (D)
/-Z2: J17.1, Q2.3 (D)
/-Z3: J14.1, Q3.3 (D)
/-Z4: J18.1, Q4.3 (D)
/AnalogOut: J5.1, R10.1
/Z1: D4.1 (K), J1.1, U1.10
/Z1sel: J7.1, Q1.1 (G), R11.2, U1.1
/Z2: D5.1 (K), J11.1, U1.6
/Z2sel: J12.1, Q2.1 (G), R12.2, U1.5
/Z3: D6.1 (K), J13.1, U3.10
/Z3sel: J19.1, Q3.1 (G), R13.2, U3.1
/Z4: D7.1 (K), J15.1, U3.6
/Z4sel: J16.1, Q4.1 (G), R14.2, U3.5
/scl: D2.4 (scl), J2.1
/sda: D2.5 (sda), J3.1
GND: C1.2, C3.2, C4.2, C5.2, C6.2, C7.2, C8.2, C11.2, C13.2, C15.2, C16.2, D1.4, D2.3 (gnd), D2.6 (ad0), D2.7 (B), D4.2 (A), D5.2 (A), D6.2 (A), D7.2 (A), J8.1, J10.1, Q1.2 (S), Q2.2 (S), Q3.2 (S), Q4.2 (S), R5.2, R11.1, R12.1, R13.1, R14.1, U1.3 (GND), U1.7, U1.9, U2.1 (GND), U3.3 (GND), U3.7, U3.9
unnamed: C2.1, D1.6 (-), R6.2
unnamed: C2.2, R3.2
unnamed: C3.1, D1.3 (+), D1.5 (+), R4.2, R5.1
unnamed: C7.1, C8.1, L2.1, U2.3 (VI)
unnamed: C9.1, R1.2
unnamed: C9.2, U1.2, U1.4, U3.2, U3.4
unnamed: D1.1, D2.8 (A), R2.1
unnamed: D1.2 (-), R1.1, R2.2
unnamed: D1.7, R6.1, R10.2
unnamed: D2.1 (W), R3.1

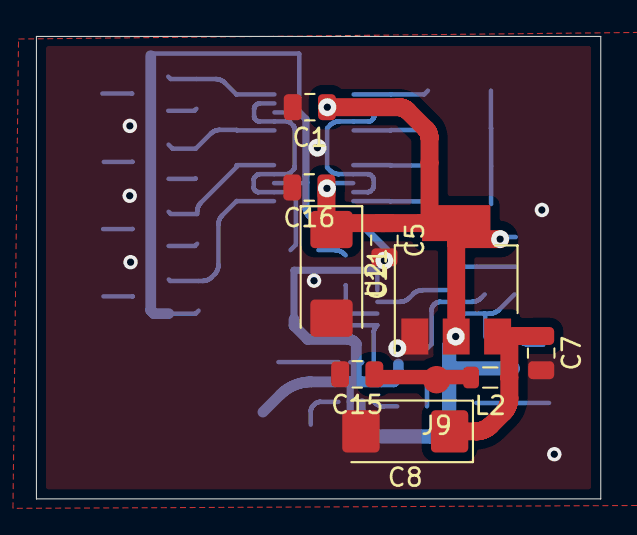
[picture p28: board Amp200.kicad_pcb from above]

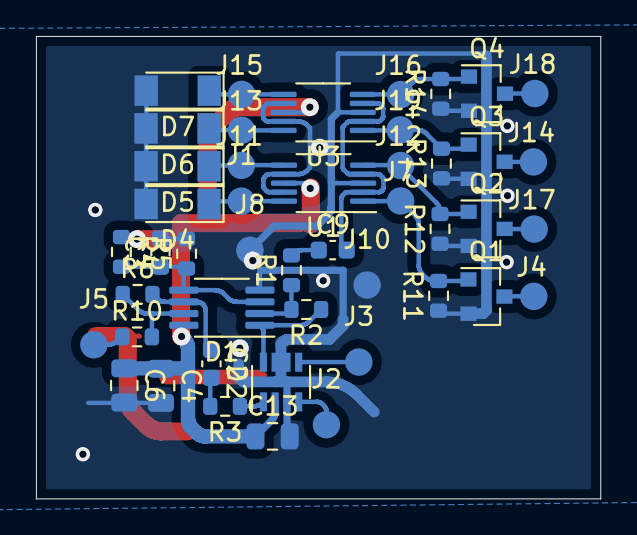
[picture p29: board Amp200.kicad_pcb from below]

Board: 2 copper layers, 31.4 x 25.7 mm, 56 parts (46 on the bottom side), 28 nets.

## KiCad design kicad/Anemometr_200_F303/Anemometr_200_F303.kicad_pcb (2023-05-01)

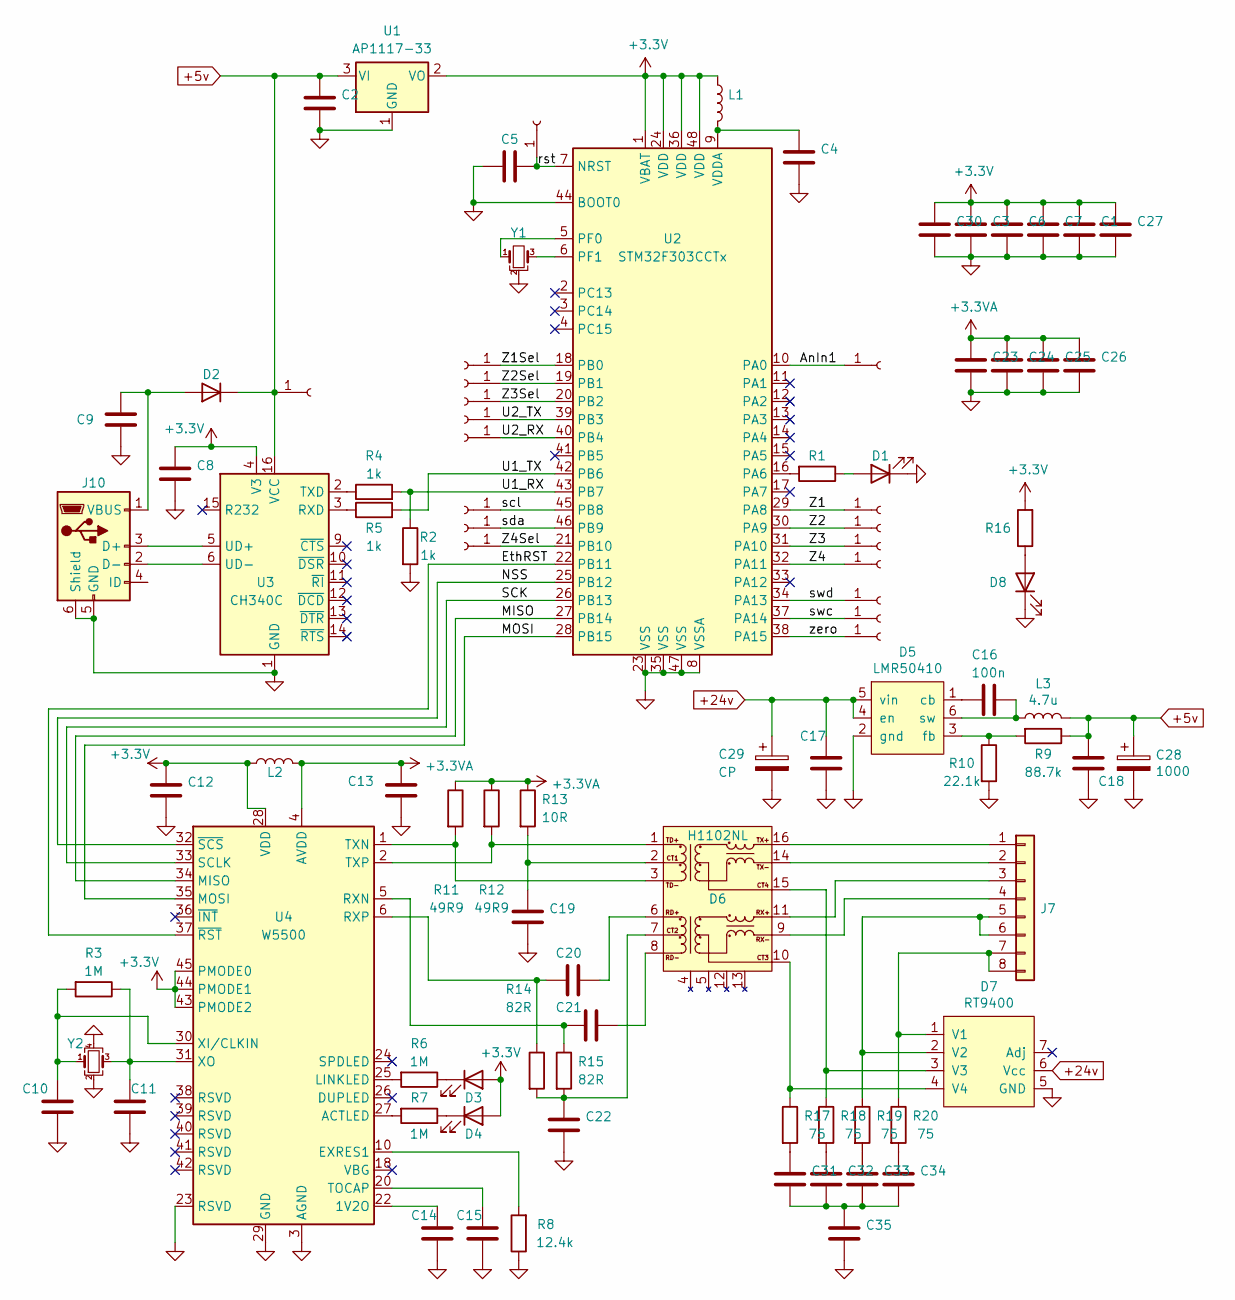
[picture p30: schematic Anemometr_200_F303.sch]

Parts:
C1, C2, C3, C4, C5, C6, C7, C8, C9, C12: C; C_0603_1608Metric
C10, C11, C13, C23, C24, C25, C26, C27: C; C_0402_1005Metric
C14, C22: 10n; C_0402_1005Metric
C15: 4.7u; C_0402_1005Metric
C16: 100n; C_0805_2012Metric
C17, C18, C30: C; C_0805_2012Metric
C19: 22n; C_0402_1005Metric
C20, C21, C31, C32, C33, C34: 6.8n; C_0402_1005Metric
C28: 1000; CP_EIA-7343-15_Kemet-W
C29: CP; CP_EIA-7343-15_Kemet-W
C35: 6.8n; C_1206_3216Metric
D1, D3, D4, D8: LED; LED_0603_1608Metric
D2: D; D_SOD-123
D5: LMR50410; SOT-23-6
D6: H1102NL; H1102N
D7: RT9400; TR9400
J1, J2, J3, J4, J5, J6, J11, J12, J13, J14, J15, J16, J17, J19, J23, J25, J26, J27: Conn_01x01_Female; mini_conn
J7: Conn_01x08; JST_SH_BM08B-SRSS-TB_1x08-1MP_P1.00mm_Vertical
J10: USB_B_Micro; USB_Micro-B_Molex_47346-0001
L1, L2: L; L_0805_2012Metric
L3: 4.7u; L_Abracon_ASPI-0630LR
R1: R; R_0603_1608Metric
R2, R4, R5, R16: 1k; R_0603_1608Metric
R3, R6, R7: 1M; R_0402_1005Metric
R8: 12.4k; R_0402_1005Metric
R9: 88.7k; R_0603_1608Metric
R10: 22.1k; R_0603_1608Metric
R11, R12: 49R9; R_0402_1005Metric
R13: 10R; R_0402_1005Metric
R14, R15: 82R; R_0402_1005Metric
R17, R18, R19, R20: 75; R_0402_1005Metric
U1: AP1117-33; SOT-223-3_TabPin2
U2: STM32F303CCTx; LQFP-48_7x7mm_P0.5mm
U3: CH340C; SOIC-16_3.9x9.9mm_P1.27mm
U4: W5500; LQFP-48_7x7mm_P0.5mm
Y1: 16MHz; Resonator_SMD_muRata_CSTxExxV-3Pin_3.0x1.1mm
Y2: Crystal_GND24_Small; Crystal_SMD_SeikoEpson_FA238-4Pin_3.2x2.5mm

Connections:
+3.3VA: C13.1, C23.1, C24.1, C25.1, C26.1, L2.2, R11.1, R12.1, R13.1, U4.4 (AVDD), U4.8 (AVDD), U4.11 (AVDD), U4.15 (AVDD), U4.17 (AVDD), U4.21 (AVDD)
+3V3: C1.1, C3.1, C6.1, C7.1, C8.1, C12.1, C27.1, C30.1, D3.2 (A), D4.2 (A), L1.1, L2.1, R16.2, U1.2 (VO), U2.1 (VBAT), U2.24 (VDD), U2.36 (VDD), U2.48 (VDD), U3.4 (V3), U4.28 (VDD), U4.43 (PMODE2), U4.44 (PMODE1), U4.45 (PMODE0)
+5v: C2.1, C18.1, C28.1, D2.1 (K), J1.1, L3.2, R9.1, U1.3 (VI), U3.16 (VCC)
+24v: C17.1, C29.1, D5.4 (en), D5.5 (vin), D7.6 (Vcc)
/AnIn1: J3.1, U2.10 (PA0)
/EthRST: U2.22 (PB11), U4.37 (~RST)
/MISO: U2.27 (PB14), U4.34 (MISO)
/MOSI: U2.28 (PB15), U4.35 (MOSI)
/NSS: U2.25 (PB12), U4.32 (~SCS)
/SCK: U2.26 (PB13), U4.33 (SCLK)
/U1_RX: R2.1, R4.2, U2.43 (PB7)
/U1_TX: R5.2, U2.42 (PB6)
/U2_RX: J25.1, U2.40 (PB4)
/U2_TX: J26.1, U2.39 (PB3)
/Z1: J13.1, U2.29 (PA8)
/Z1Sel: J2.1, U2.18 (PB0)
/Z2: J15.1, U2.30 (PA9)
/Z2Sel: J4.1, U2.19 (PB1)
/Z3: J17.1, U2.31 (PA10)
/Z3Sel: J6.1, U2.20 (PB2)
/Z4: J19.1, U2.32 (PA11)
/Z4Sel: J16.1, U2.21 (PB10)
/rst: C5.1, J11.1, U2.7 (NRST)
/scl: J12.1, U2.45 (PB8)
/sda: J14.1, U2.46 (PB9)
/swc: J23.1, U2.37 (PA14)
/swd: J27.1, U2.34 (PA13)
/zero: J5.1, U2.38 (PA15)
GND: C1.2, C2.2, C3.2, C4.2, C5.2, C6.2, C7.2, C8.2, C9.2, C10.2, C11.2, C12.2, C13.2, C14.2, C15.2, C17.2, C18.2, C19.2, C22.2, C23.2, C24.2, C25.2, C26.2, C27.2, C28.2, C29.2, C30.2, C35.2, D1.1 (K), D5.2 (gnd), D7.5 (GND), D8.1 (K), J10.5 (GND), J10.6 (Shield), R2.2, R8.1, R10.2, U1.1 (GND), U2.8 (VSSA), U2.23 (VSS), U2.35 (VSS), U2.44 (BOOT0), U2.47 (VSS), U3.1 (GND), U4.3 (AGND), U4.9 (AGND), U4.14 (AGND), U4.16 (AGND), U4.19 (AGND), U4.23 (RSVD), U4.29 (GND), U4.48 (AGND), Y1.2, Y2.2, Y2.4
unnamed: C4.1, L1.2, U2.9 (VDDA)
unnamed: C9.1, D2.2 (A), J10.1 (VBUS)
unnamed: C10.1, R3.2, U4.30 (XI/CLKIN), Y2.1
unnamed: C11.1, R3.1, U4.31 (XO), Y2.3
unnamed: C14.1, U4.22 (1V2O)
unnamed: C15.1, U4.20 (TOCAP)
unnamed: C16.1, D5.6 (sw), L3.1
unnamed: C16.2, D5.1 (cb)
unnamed: C19.1, D6.2, R13.2
unnamed: C20.1, D6.6
unnamed: C20.2, R14.1, U4.6 (RXP)
unnamed: C21.1, D6.8
unnamed: C21.2, R15.1, U4.5 (RXN)
unnamed: C22.1, D6.7, R14.2, R15.2
unnamed: C31.1, R17.2
unnamed: C31.2, C32.2, C33.2, C34.2, C35.1
unnamed: C32.1, R18.2
unnamed: C33.1, R19.2
unnamed: C34.1, R20.2
unnamed: D1.2 (A), R1.1
unnamed: D3.1 (K), R6.1
unnamed: D4.1 (K), R7.1
unnamed: D5.3 (fb), R9.2, R10.1
unnamed: D6.1, R12.2, U4.2 (TXP)
unnamed: D6.3, R11.2, U4.1 (TXN)
unnamed: D6.9, J7.4
unnamed: D6.10, D7.4 (V4), R17.1
unnamed: D6.11, J7.3
unnamed: D6.14, J7.2
unnamed: D6.15, D7.3 (V3), R18.1
unnamed: D6.16, J7.1
unnamed: D7.1 (V1), J7.7, J7.8, R20.1
unnamed: D7.2 (V2), J7.5, J7.6, R19.1
unnamed: D8.2 (A), R16.1
unnamed: J10.2 (D-), U3.6 (UD-)
unnamed: J10.3 (D+), U3.5 (UD+)
unnamed: R1.2, U2.16 (PA6)
unnamed: R4.1, U3.2 (TXD)
unnamed: R5.1, U3.3 (RXD)
unnamed: R6.2, U4.25 (LINKLED)
unnamed: R7.2, U4.27 (ACTLED)
unnamed: R8.2, U4.10 (EXRES1)
unnamed: U2.5 (PF0), Y1.1
unnamed: U2.6 (PF1), Y1.3

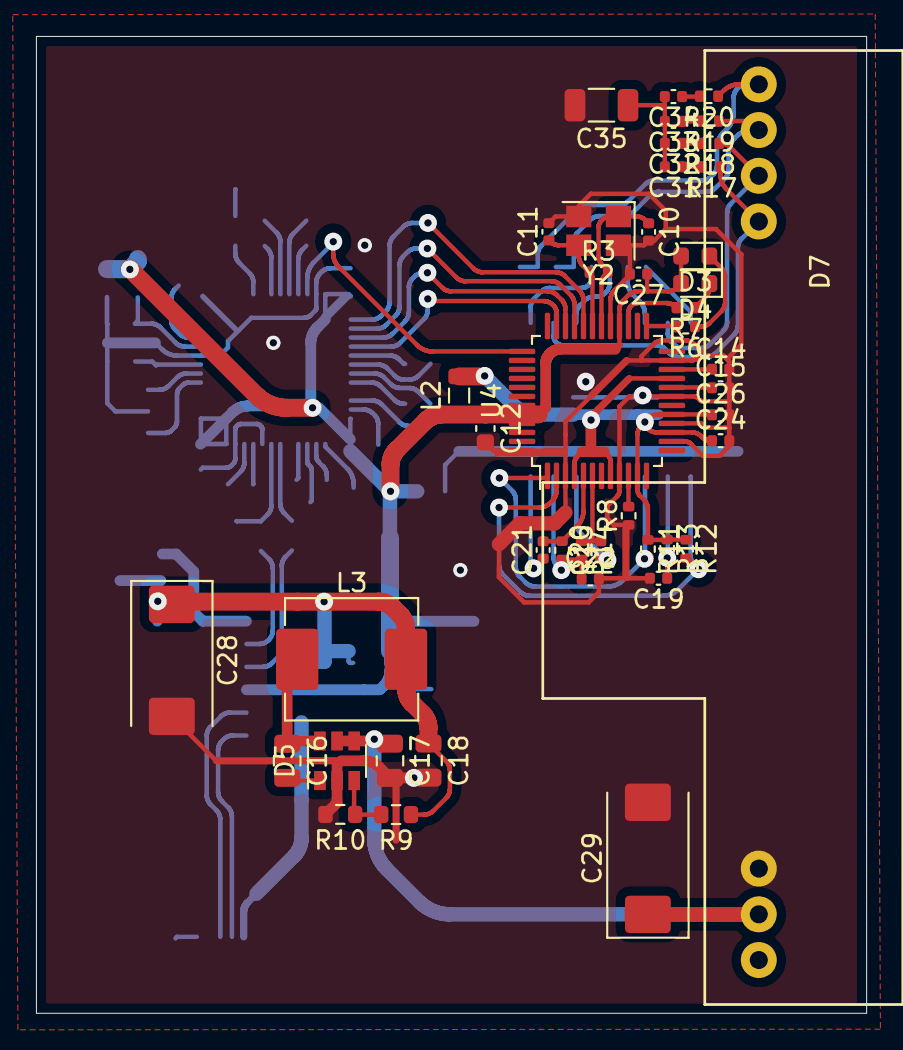
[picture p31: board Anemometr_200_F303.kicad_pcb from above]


Board: 2 copper layers, 46.1 x 54.3 mm, 92 parts (47 on the bottom side), 73 nets.

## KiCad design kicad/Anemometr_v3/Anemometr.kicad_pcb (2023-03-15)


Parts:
C1, C15, C55, C56: 10uF; C_0603_1608Metric
C2: 470uF x 6.3v; CP_EIA-7343-15_Kemet-W
C3, C14, C27, C28, C31, C35, C38, C39: 0.1uF; C_0402_1005Metric
C4, C7: 10p; C_0402_1005Metric
C8, C9, C11, C13: 0.1uF; C_0603_1608Metric
C10, C16: 10nF; C_0402_1005Metric
C12: 4.7uF; C_0402_1005Metric
C19: 22uF/63v; CP_Elec_6.3x7.7
C20: 22nF; C_0402_1005Metric
C22, C23, C24, C30, C36, C37: 10uF; C_0805_2012Metric
C25, C26, C42, C45, C46, C48: 6.8nF; C_0402_1005Metric
C29: 28p; C_0603_1608Metric
C33: 480p; C_0603_1608Metric
C43: 1uF; C_0402_1005Metric
C44: 10nF; C_0603_1608Metric
C49: 4.7nF/2kV; C_1206_3216Metric
C50: 220uF; CP_EIA-7343-15_Kemet-W
C53: 100n; C_0805_2012Metric
C54: 22uF; C_0805_2012Metric
C58: 1000uF; CP_EIA-7343-15_Kemet-W
D1: Act; LED_0603_1608Metric
D2: Link; LED_0603_1608Metric
D3: W5500; LQFP-48_7x7mm_P0.5mm
D4, D5: LED; LED_0603_1608Metric
D6: MM1Z27; D_SOD-123
D8, D13: F7; D_SOD-123
D9: BZT52-C15; D_SOD-123
D10: H1102NL; H1102N
D11: ?U6119SA?; SOIC-8-N7_3.9x4.9mm_P1.27mm
D12, D15: MB6S; TO-269AA
D14: ?T4932B?; DA2257
D16: SS34; D_SOD-123
D17: SS56, VS10MQ060-M3/5; D_SMA
D18: MC33375ST; SOT-223
J1: TxD; ConnMini
J2: RxD; ConnMini
J3: JST-SH1.0; JST_SH_BM04B-SRSS-TB_1x04-1MP_P1.00mm_Vertical
J4: JST-SH1.0; JST_SH_BM08B-SRSS-TB_1x08-1MP_P1.00mm_Vertical
J5: RST; ConnMini
J6: +EXT; SMD-CONN
J7: -EXT; SMD-CONN
J8: SWD; ConnMini
J9: SWC; ConnMini
J10, J28, J29, J30, J31, J32, J33, J34, J35: +Z1; ConnMini
J11: +Z2; ConnMini
J12: +Z3; ConnMini
J13: +Z4; ConnMini
J14: -Z1; SMD-CONN
J15: -Z2; SMD-CONN
J16: -Z3; SMD-CONN
J17: -Z4; SMD-CONN
J24, J25, J26, J27, J36, J37, J38, J39: +Z1; SMD-CONN
L1: HH-1M1608-121JT; L_0603_1608Metric
L2: 47uH; L_0805_2012Metric
L5: 15uH; L_Abracon_ASPI-0630LR
Q1: 5N10; SOT-23
R1: 1M; R_0402_1005Metric
R2, R3, R4: 1k; R_0402_1005Metric
R9, R10: 49R9; R_0402_1005Metric
R11: 12.4k; R_0402_1005Metric
R12, R14: 82R; R_0402_1005Metric
R15: 4.7k; R_0402_1005Metric
R18: 10R; R_0402_1005Metric
R19: 100k; R_0603_1608Metric
R21: 43k; R_0603_1608Metric
R22, R34: 10k; R_0603_1608Metric
R23: 51k; R_0603_1608Metric
R24: 237k; R_0603_1608Metric
R26: 20R; R_0603_1608Metric
R27: 47R; R_0603_1608Metric
R28: 0.68; R_0603_1608Metric
R30, R41: 24k; R_0603_1608Metric
R32, R35, R36, R40: 75; R_0402_1005Metric
R42: 150k; R_0603_1608Metric
U1: STM32F103C8Tx; LQFP-48_7x7mm_P0.5mm
U4: LMR14206; SOT-23-6
U6: NCP1117-3.3; SOT-223-3_TabPin2
U9: MCP1703-3.3; SOT-23
Y1: CSTCE8M00G52A-R0; Resonator_SMD_muRata_CSTxExxV-3Pin_3.0x1.1mm
Y2: ECS-250-20-33; Crystal_SMD_SeikoEpson_FA238-4Pin_3.2x2.5mm

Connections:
6v: C22.2, C36.2, C54.2, C58.1, L2.1, L5.2, R15.2, R42.1, U6.3 (VI), U9.3 (VI)
12v: C1.2, C30.2, C50.1, D16.1 (K), U4.4 (~SHDN), U4.5 (VIN)
+3.3VA: C2.1, C27.1, C28.1, C31.1, C35.1, C38.1, C39.1, C43.1, D3.4 (AVDD), D3.8 (AVDD), D3.11 (AVDD), D3.15 (AVDD), D3.17 (AVDD), D3.21 (AVDD), L1.2, R9.2, R10.2, R18.2
+3.3VDAC: C14.2, C15.2, C56.2, D1.2 (A), D2.2 (A), D3.28 (VDD), D3.43 (PMODE2), D3.44 (PMODE1), D3.45 (PMODE0), L1.1, U6.2 (VO)
+3V3: C8.1, C9.1, C11.1, C13.1, C37.2, J3.4, J6.1, U1.1 (VBAT), U1.9 (VDDA), U1.24 (VDD), U1.36 (VDD), U1.48 (VDD), U9.2 (VO)
+5VA: C55.2, D18.3 (Vout), J24.1, J25.1, J26.1, J27.1
/4-5: D15.2 (~~), J4.5, J4.6, R36.2
/7-8: D15.1 (~~), J4.7, J4.8, R40.2
/+Z1: J10.1, U1.29 (PA8)
/+Z2: J11.1, U1.30 (PA9)
/+Z3: J12.1, U1.31 (PA10)
/+Z4: J13.1, U1.32 (PA11)
/Rst: C3.2, J5.1, U1.7 (NRST)
/RxD: J2.1, U1.43 (PB7)
/RxD+: D10.11, J4.3
/RxD-: D10.9, J4.4
/SCL: J3.2, U1.45 (PB8)
/SDA: J3.1, U1.46 (PB9)
/TxD: J1.1, U1.42 (PB6)
/TxD+: D10.16, J4.1
/TxD-: D10.14, J4.2
/swc: J9.1, U1.37 (PA14)
/swd: J8.1, U1.34 (PA13)
GND: C1.1, C2.2, C3.1, C4.2, C7.2, C8.2, C9.2, C10.1, C11.2, C12.1, C13.2, C14.1, C15.1, C16.1, C20.2, C22.1, C23.1, C27.2, C28.2, C30.1, C31.2, C35.2, C36.1, C37.1, C38.2, C39.2, C43.2, C49.1, C50.2, C54.1, C55.1, C56.1, C58.2, D3.3 (AGND), D3.9 (AGND), D3.14 (AGND), D3.16 (AGND), D3.19 (AGND), D3.23 (RSVD), D3.29 (GND), D3.48 (AGND), D4.1 (K), D5.1 (K), D14.9, D14.10, D17.2 (A), D18.4 (Gnd), J3.3, J3.MP (MountPin), J4.MP (MountPin), J7.1, J14.1, J15.1, J16.1, J17.1, J36.1, J37.1, J38.1, J39.1, R11.1, R41.2, U1.8 (VSSA), U1.23 (VSS), U1.35 (VSS), U1.44 (BOOT0), U1.47 (VSS), U4.2 (GND), U6.1 (GND), U9.1 (GND), Y1.2, Y2.2, Y2.4
unnamed: C4.1, D3.31 (XO), R1.2, Y2.1
unnamed: C7.1, D3.30 (XI), R1.1, Y2.3
unnamed: C10.2, D3.22 (1V20)
unnamed: C12.2, D3.20 (TOCAP)
unnamed: C16.2, D10.7, R12.1, R14.1
unnamed: C19.1, C44.1, D6.1 (K), D12.3 (+), D14.4, D14.5, D15.3 (+), R19.1, R30.1, R34.1
unnamed: C19.2, C24.2, C29.2, C33.2, D11.8 (GND), D14.1, Q1.3 (D), R22.2, R28.2
unnamed: C20.1, D10.2, R18.1
unnamed: C23.2, D18.1 (Vin), D18.2 (On), L2.2
unnamed: C24.1, D11.1 (VCC), R19.2, R26.2
unnamed: C25.1, D3.6 (RxP), R12.2
unnamed: C25.2, D10.6
unnamed: C26.1, D3.5 (RxN), R14.2
unnamed: C26.2, D10.8
unnamed: C29.1, D11.3 (FB), R21.2, R22.1
unnamed: C33.1, R27.2
unnamed: C42.1, R32.1
unnamed: C42.2, C45.2, C46.2, C48.2, C49.2
unnamed: C44.2, D13.1 (K), R34.2
unnamed: C45.1, R35.1
unnamed: C46.1, R36.1
unnamed: C48.1, R40.1
unnamed: C53.1, D17.1 (K), L5.1, U4.6 (SW)
unnamed: C53.2, U4.1 (CB)
unnamed: D1.1 (K), R2.1
unnamed: D2.1 (K), R3.1
unnamed: D3.10 (EXRES1), R11.2
unnamed: D3.25 (LINKED), R3.2
unnamed: D3.27 (ACTLED), R2.2
unnamed: D4.2 (A), R4.1
unnamed: D5.2 (A), R15.1
unnamed: D6.2 (A), R23.2
unnamed: D8.1 (K), R26.1
unnamed: D9.1 (K), Q1.1 (G), R23.1, R24.1
unnamed: D3.2 (TxP), D10.1, R10.1
unnamed: D3.1 (TxN), D10.3, R9.1
unnamed: D10.10, D12.2 (~~), R32.2
unnamed: D10.15, D12.1 (~~), R35.2
unnamed: D11.2 (COMP), R27.1
unnamed: D11.4 (CS), R28.1
unnamed: D11.5 (SW), D11.6 (SW), D13.2 (A), D14.3
unnamed: D9.2 (A), D12.4 (-), D15.4 (-), Q1.2 (S), R24.2, R30.2
unnamed: D8.2 (A), D14.2, R21.1
unnamed: D14.6, D14.7, D14.8, D16.2 (A)
unnamed: R4.2, U1.17 (PA7)
unnamed: R41.1, R42.2, U4.3 (FB)
unnamed: U1.5 (PD0), Y1.1
unnamed: U1.6 (PD1), Y1.3
SIn: J28.1, J29.1, J30.1, J31.1, U1.10 (PA0)
Z1Sel: J32.1, U1.19 (PB1)
Z2Sel: J33.1, U1.20 (PB2)
Z3Sel: J34.1, U1.39 (PB3)
Z4Sel: J35.1, U1.40 (PB4)
miso: D3.34 (MISO), U1.27 (PB14)
mosi: D3.35 (MOSI), U1.28 (PB15)
nrst: D3.37 (RSTn), U1.33 (PA12)
sclk: D3.33 (SCLK), U1.26 (PB13)
scsn: D3.32 (SCSn), U1.25 (PB12)



Board: 2 copper layers, 45.0 x 45.0 mm, 132 parts (46 on the bottom side), 82 nets.

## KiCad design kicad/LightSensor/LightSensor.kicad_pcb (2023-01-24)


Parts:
C1: 1uF; C_0402_1005Metric
C2: 0.1uF; C_0402_1005Metric
D1: BH1750FVI
J1, J2, J3, J4: Conn; ConnMini
R1, R2: 5.1k; R_0402_1005Metric
R3: 1k; R_0402_1005Metric

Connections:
GND: C1.2, C2.2, D1.2 (Addr), D1.3 (Gnd), J4.1
unnamed: C1.1, D1.5 (Dvi), R3.2
unnamed: C2.1, D1.1 (Vcc), J1.1, R1.1, R2.1, R3.1
unnamed: D1.4 (Sda), J3.1, R1.2
unnamed: D1.6 (Scl), J2.1, R2.2


Board: 2 copper layers, 9.0 x 6.9 mm, 10 parts (10 on the bottom side), 5 nets.

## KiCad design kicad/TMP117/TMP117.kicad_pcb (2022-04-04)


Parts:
C1: 0.1uF; C_0402_1005Metric
D1: TMP117
J1: Vcc; SMD-CONN
J2: SCL; SMD-CONN
J3: SDA; SMD-CONN
J4: GND; SMD-CONN
R1, R2: 5.1k; R_0402_1005Metric

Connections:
GND: C1.2, D1.2 (Gnd), D1.4 (Add0), D1.7, J4.1
unnamed: C1.1, D1.5 (Vcc), J1.1, R1.1, R2.1
unnamed: D1.1 (SCL), J2.1, R2.2
unnamed: D1.6 (SDA), J3.1, R1.2


Board: 2 copper layers, 7.8 x 4.5 mm, 8 parts (8 on the bottom side), 4 nets.

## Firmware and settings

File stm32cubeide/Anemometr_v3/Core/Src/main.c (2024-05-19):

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
/* Includes ------------------------------------------------------------------*/
#include "main.h"

I2C_HandleTypeDef hi2c1;

IWDG_HandleTypeDef hiwdg;

SPI_HandleTypeDef hspi2;

TIM_HandleTypeDef htim1;
TIM_HandleTypeDef htim2;
TIM_HandleTypeDef htim3;
TIM_HandleTypeDef htim4;

UART_HandleTypeDef huart1;

/* USER CODE BEGIN PV */
HAL_StatusTypeDef	flash_ok;
char uart_buffer[10] = {0,};
char SndBuffer[200] = {0,};
wiz_NetInfo net_info = {
	.mac  = { MAC_ADDRESS },
	.dhcp = NETINFO_DHCP
};
uint32_t errCnt, errMin, errMax, err;
/* USER CODE END PV */

void SystemClock_Config(void);
static void MX_GPIO_Init(void);
static void MX_USART1_UART_Init(void);
static void MX_TIM1_Init(void);
static void MX_TIM4_Init(void);
static void MX_TIM3_Init(void);
static void MX_TIM2_Init(void);
static void MX_I2C1_Init(void);
static void MX_SPI2_Init(void);
static void MX_IWDG_Init(void);
/* USER CODE BEGIN 0 */
void rwFlash(uint8_t rwFlag) {
	uint32_t pageAdr = 0x800FC00; //.
	uint32_t magicKey;
	uint64_t dataForSave;
	magicKey = *(__IO uint32_t*) pageAdr;
	if ((magicKey != 0x12349876) || (rwFlag == 1)) { // rwFlag == 1 for wrtite data to flash
		magicKey = 0x12349876;
		if (rwFlag == 0) { // For first initial
			C_1 = CALIBRATE_START;
			C_3 = CALIBRATE_START;
			C_2 = CALIBRATE_START;
			C_4 = CALIBRATE_START;
			t0.f = 20.0;  /* Около комнатной температуры */
			DX1.f = 1;
			//DX2.f = 1;
			DY1.f = 1;
			//DY2.f = 1;
		}
		FLASH_EraseInitTypeDef EraseInitStruct;
		uint32_t PAGEError = 0;
		EraseInitStruct.TypeErase   = FLASH_TYPEERASE_PAGES;
		EraseInitStruct.PageAddress = pageAdr; //
		EraseInitStruct.NbPages     = 1;

		flash_ok = HAL_ERROR;
		// Unlock flash
		while(flash_ok != HAL_OK) {
		  flash_ok = HAL_FLASH_Unlock();
		}
		if (HAL_FLASHEx_Erase(&EraseInitStruct, &PAGEError) == HAL_OK) {
			dataForSave = (uint64_t) magicKey;
			flash_ok = HAL_ERROR;
			while(flash_ok != HAL_OK){
				flash_ok = HAL_FLASH_Program(FLASH_TYPEPROGRAM_DOUBLEWORD, pageAdr, dataForSave); // Write  magic key
			}
			dataForSave = (uint64_t) (C_1 | ((uint64_t) C_2 << 16) | ((uint64_t) C_3 << 32) | ((uint64_t) C_4 << 48));
			flash_ok = HAL_ERROR;
			while(flash_ok != HAL_OK){
				flash_ok = HAL_FLASH_Program(FLASH_TYPEPROGRAM_DOUBLEWORD, pageAdr + 16, dataForSave); // Write C_12 C_34 C_14 C_23
			}
			flash_ok = HAL_ERROR;
			while(flash_ok != HAL_OK){
				flash_ok = HAL_FLASH_Program(FLASH_TYPEPROGRAM_WORD, pageAdr + 24, DX1.u); // Write DX1
			}
			//flash_ok = HAL_ERROR;
			//while(flash_ok != HAL_OK){
			//	flash_ok = HAL_FLASH_Program(FLASH_TYPEPROGRAM_WORD, pageAdr + 28, DX2.u); // Write DX2
			//}
			flash_ok = HAL_ERROR;
			while(flash_ok != HAL_OK){
				flash_ok = HAL_FLASH_Program(FLASH_TYPEPROGRAM_WORD, pageAdr + 32, DY1.u); // Write DY1
			}
			flash_ok = HAL_ERROR;
			while(flash_ok != HAL_OK){
				flash_ok = HAL_FLASH_Program(FLASH_TYPEPROGRAM_WORD, pageAdr + 36, t0.u); // Сохраним температуру калибровки
			}
		}
		// Lock flash
		flash_ok = HAL_ERROR;
		while(flash_ok != HAL_OK){
			flash_ok = HAL_FLASH_Lock();
		}
	} else {
		/* Задержки измерения в каналах */
		C_1 = *(__IO uint16_t*) (pageAdr + 16);
		C_2 = *(__IO uint16_t*) (pageAdr + 18);
		C_3 = *(__IO uint16_t*) (pageAdr + 20);
		C_4 = *(__IO uint16_t*) (pageAdr + 22);
		/* Значения для температурной калибровки */
		C_Y = C_3;
		C_X = C_4;
		memset(SndBuffer, 0, sizeof(SndBuffer));
		sprintf(SndBuffer, "C_1: %5d, C_2: %5d, C_3: %5d, C_4: %5d  \r\n", C_1, C_2, C_3, C_4);
		HAL_UART_Transmit(&huart1, (uint8_t *) SndBuffer, sizeof(SndBuffer), 1000);

		/* Поправочные коэффициенты */
		DX1.u = *(__IO uint32_t*) (pageAdr + 24);
		//DX2.u = *(__IO uint32_t*) (pageAdr + 28);
		DY1.u = *(__IO uint32_t*) (pageAdr + 32);
		memset(SndBuffer, 0, sizeof(SndBuffer));
		sprintf(SndBuffer, "DX1: %7.6f, DY1: %7.6f \r\n", DX1.f, DY1.f);
		HAL_UART_Transmit(&huart1, (uint8_t *) SndBuffer, sizeof(SndBuffer), 1000);
		t0.u = *(__IO uint32_t*) (pageAdr + 36);	// Восстановим температуру калибровки
		if (t0.u == 0xffffffff) {  // Начальная температура не определена.
			t0.f = 20.0;
		}
		memset(SndBuffer, 0, sizeof(SndBuffer));
		sprintf(SndBuffer, "T0: %5.2f \r\n", t0.f);
		HAL_UART_Transmit(&huart1, (uint8_t *) SndBuffer, sizeof(SndBuffer), 1000);
	}
}

#ifdef ZABBIX_ENABLE

#ifdef ZABBIX_DEBUG
void UART_Printf(const char* fmt, ...) {
	char buff[256];
	va_list args;
	va_start(args, fmt);
	vsnprintf(buff, sizeof(buff), fmt, args);
	HAL_UART_Transmit(&huart1, (uint8_t*) buff, strlen(buff), HAL_MAX_DELAY);
	va_end(args);
}
#endif


void W5500_Select(void) {
	HAL_GPIO_WritePin(SCSN_GPIO_Port, SCSN_Pin, GPIO_PIN_RESET);
}

void W5500_Unselect(void) {
	HAL_GPIO_WritePin(SCSN_GPIO_Port, SCSN_Pin, GPIO_PIN_SET);
}

void W5500_ReadBuff(uint8_t* buff, uint16_t len) {
	HAL_SPI_Receive(&hspi2, buff, len, HAL_MAX_DELAY);
}

void W5500_WriteBuff(uint8_t* buff, uint16_t len) {
	HAL_SPI_Transmit(&hspi2, buff, len, HAL_MAX_DELAY);
}

uint8_t W5500_ReadByte(void) {
	uint8_t byte;
	W5500_ReadBuff(&byte, sizeof(byte));
	return byte;
}

void W5500_WriteByte(uint8_t byte) {
	W5500_WriteBuff(&byte, sizeof(byte));
}

volatile bool ip_assigned = false;

void Callback_IPAssigned(void) {
#ifdef ZABBIX_DEBUG
	UART_Printf("Callback: IP assigned! Leased time: %d sec\r\n", getDHCPLeasetime());
#endif
    ip_assigned = true;
}

void Callback_IPConflict(void) {
#ifdef ZABBIX_DEBUG
    UART_Printf("Callback: IP conflict!\r\n");
#endif
}

// 1K should be enough, see https://forum.wiznet.io/t/topic/1612/2
uint8_t dhcp_buffer[1024];
// 1K seems to be enough for this buffer as well
//uint8_t dns_buffer[1024];

/*
 * addr -- IP address zabbix server, dhcp option 224.
 * Settings for isc-dhcp-server:
 * 		option zabbix-server-ip code 224 = ip-address ;
 * 		option zabix-host-name code 225 = string ;
 * 		host anemometr {
 *      	hardware ethernet 00:11:22:33:44:xx;
 *      	fixed-address 192.168.1.24;
 *       	option zabbix-server-ip 192.168.1.6;
 *       	option zabix-host-name "Ed";
 * 		}
 *
 * key -- Zabbix key: {ALTIM_DIRECT, ALTIM_SPEED}
 *
 * value -- Float value of key.
*/
uint8_t sendToZabbix(uint8_t * addr, char * host, char * key, float value) {
#ifdef ZABBIX_DEBUG
    UART_Printf("Creating socket...\r\n");
#endif
    uint8_t tcp_socket = TCP_SOCKET;
    uint8_t code = socket(tcp_socket, Sn_MR_TCP, 10888, 0);
    if(code != tcp_socket) {
    	eternetErrorCount++;
	#ifdef ZABBIX_DEBUG
        UART_Printf("socket() failed, code = %d\r\n", code);
	#endif
        return(-1);
    } else {
    	eternetErrorCount = 0;
    }
#ifdef ZABBIX_DEBUG
    UART_Printf("Socket created, connecting...\r\n");
#endif
    code = connect(tcp_socket, addr, ZABBIXPORT);
    if(code != SOCK_OK) {
    	eternetErrorCount++;
	#ifdef ZABBIX_DEBUG
        UART_Printf("connect() failed, code = %d\r\n", code);
	#endif
        close(tcp_socket);
        return(-2);
    } else {
    	eternetErrorCount = 0;
    }
#ifdef ZABBIX_DEBUG
    UART_Printf("Connected, sending ZABBIX request...\r\n");
#endif
    {
    	char req[ZABBIXMAXLEN];
    	char str[ZABBIXMAXLEN - 13];
    	sprintf(str, "{\"request\":\"sender data\",\"data\":[{\"host\":\"%.20s\",\"key\":\"%s\",\"value\":\"%f\"}]}", host, key, value);
    	req[0] = 'Z';
    	req[1] = 'B';
		req[2] = 'X';
		req[3] = 'D';
		req[4] = 0x01;
		req[5] = strlen(str);
		req[6] = 0;
		req[7] = 0;
		req[8] = 0;
		req[9] = 0;
		req[10] = 0;
		req[11] = 0;
		req[12] = 0;
		strcpy(req + 13, str);
        //char req[] = "ZBXD\1\0\0\0\0\0\0\0\0{\"request\":\"sender data\",\"data\":[{\"host\":\"Ed\",\"key\":\"ALTIM_DIRECT\",\"value\":\"10\"}]}";
        uint8_t len = req[5] + 13;
        uint8_t* buff = (uint8_t*)&req;
        while(len > 0) {
		#ifdef ZABBIX_DEBUG
            UART_Printf("Sending %d bytes, data length %d bytes...\r\n", len, req[5]);
		#endif
            int32_t nbytes = send(tcp_socket, buff, len);
            if(nbytes <= 0) {
            	eternetErrorCount++;
			#ifdef ZABBIX_DEBUG
                UART_Printf("send() failed, %d returned\r\n", nbytes);
			#endif
                close(tcp_socket);
                return(-3);
            } else {
            	eternetErrorCount = 0;
            }
			#ifdef ZABBIX_DEBUG
            UART_Printf("%d b sent!\r\n", nbytes);
			#endif
            len -= nbytes;
        }
    }
    /* Read data from Zabbix */
	#ifdef ZABBIX_DEBUG
		UART_Printf("Read.\r\n");
		{
			char buff[32];
			for(;;) {
				int32_t nbytes = recv(tcp_socket, (uint8_t*)&buff, sizeof(buff)-1);
				if(nbytes == SOCKERR_SOCKSTATUS) {
					UART_Printf("\r\nDisconnect.\r\n");
					break;
				}

				if(nbytes <= 0) {
					UART_Printf("\r\nrecv() failed, %d\r\n", nbytes);
					break;
				}

				buff[nbytes] = '\0';
				UART_Printf("%s", buff);
			}
		}

		UART_Printf("Closing socket.\r\n");
	#endif
    close(tcp_socket);
    return(0);
}



void init_w5500() {
	#ifdef ZABBIX_DEBUG
    UART_Printf("\r\ninit() called!\r\n");
    UART_Printf("Registering W5500 callbacks...\r\n");
	#endif
    reg_wizchip_cs_cbfunc(W5500_Select, W5500_Unselect);
    reg_wizchip_spi_cbfunc(W5500_ReadByte, W5500_WriteByte);
    reg_wizchip_spiburst_cbfunc(W5500_ReadBuff, W5500_WriteBuff);
	#ifdef ZABBIX_DEBUG
    UART_Printf("Calling wizchip_init()...\r\n");
	#endif
    uint8_t rx_tx_buff_sizes[] = {2, 2, 2, 2, 2, 2, 2, 2};
    wizchip_init(rx_tx_buff_sizes, rx_tx_buff_sizes);
	#ifdef ZABBIX_DEBUG
    UART_Printf("Calling DHCP_init()...\r\n");
	#endif

    // set MAC address before using DHCP
    setSHAR(net_info.mac);
    DHCP_init(DHCP_SOCKET, dhcp_buffer);
	#ifdef ZABBIX_DEBUG
    UART_Printf("Registering DHCP callbacks...\r\n");
	#endif
    reg_dhcp_cbfunc(
        Callback_IPAssigned,
        Callback_IPAssigned,
        Callback_IPConflict
    );
	#ifdef ZABBIX_DEBUG
    UART_Printf("Calling DHCP_run()...\r\n");
	#endif
    // actually should be called in a loop, e.g. by timer
    uint32_t ctr = DHCP_TRY_CNT;
    while((!ip_assigned) && (ctr > 0)) {
        DHCP_run();
        ctr--;
        HAL_Delay(100);
        HAL_IWDG_Refresh(&hiwdg);
    }
    if(!ip_assigned) {
		#ifdef ZABBIX_DEBUG
        UART_Printf(DHCP_ERROR_ASSIGN);
		#endif
        NVIC_SystemReset();
        return;
    }

    getIPfromDHCP(net_info.ip);
    getGWfromDHCP(net_info.gw);
    getSNfromDHCP(net_info.sn);
    getZABBIXfromDHCP(net_info.zabbix);
    getHostNamefromDHCP(net_info.hostname);
    if (net_info.hostname[0] == '\0') {
    	sprintf(ZabbixHostName, "%s", ZABBIXAGHOST);
    } else {
    	sprintf(ZabbixHostName, "%s", net_info.hostname);
    }

    //uint8_t dns[4];
    //getDNSfromDHCP(dns);
	#ifdef ZABBIX_DEBUG
    UART_Printf("IP:  %d.%d.%d.%d\r\nGW:  %d.%d.%d.%d\r\nNet: %d.%d.%d.%d\r\nZabbix: %d.%d.%d.%d\r\nHostName:%s\r\n",
        net_info.ip[0], net_info.ip[1], net_info.ip[2], net_info.ip[3],
        net_info.gw[0], net_info.gw[1], net_info.gw[2], net_info.gw[3],
        net_info.sn[0], net_info.sn[1], net_info.sn[2], net_info.sn[3],
        net_info.zabbix[0], net_info.zabbix[1], net_info.zabbix[2], net_info.zabbix[3],
		ZabbixHostName
    );
    UART_Printf("Calling wizchip_setnetinfo()...\r\n");
	#endif
    wizchip_setnetinfo(&net_info);

}
#endif
/* USER CODE END 0 */

/**
  * @brief  The application entry point.
  * @retval int
  */
int main(void)
{
  /* MCU Configuration--------------------------------------------------------*/

  /* Reset of all peripherals, Initializes the Flash interface and the Systick. */
  HAL_Init();

  /* USER CODE BEGIN Init */
	sprintf(SndBuffer, "\r\nLow power: %s, WWD: %s, IWD: %s, Soft: %s, Pin: %s, Power: %s\r\n",
			(__HAL_RCC_GET_FLAG(RCC_FLAG_LPWRRST)) ? "Yes" : "No",
			(__HAL_RCC_GET_FLAG(RCC_FLAG_WWDGRST)) ? "Yes" : "No",
			(__HAL_RCC_GET_FLAG(RCC_FLAG_IWDGRST)) ? "Yes" : "No",
			(__HAL_RCC_GET_FLAG(RCC_FLAG_SFTRST)) ? "Yes" : "No",
			(__HAL_RCC_GET_FLAG(RCC_FLAG_PINRST)) ? "Yes" : "No",
			(__HAL_RCC_GET_FLAG(RCC_FLAG_PORRST)) ? "Yes" : "No");

  /* USER CODE END Init */

  /* Configure the system clock */
  SystemClock_Config();

  /* Initialize all configured peripherals */
  MX_GPIO_Init();
  MX_USART1_UART_Init();
  MX_TIM1_Init();
  MX_TIM4_Init();
  MX_TIM3_Init();
  MX_TIM2_Init();
  MX_I2C1_Init();
  MX_SPI2_Init();
  MX_IWDG_Init();
  /* USER CODE BEGIN 2 */
  HAL_GPIO_WritePin(LED_GPIO_Port, LED_Pin, GPIO_PIN_SET);
  readyFlag = TRUE;
  //sumCounter2 = 0;
  HAL_UART_Transmit(&huart1, (uint8_t *) SndBuffer, sizeof(SndBuffer), HAL_MAX_DELAY);
  HAL_UART_Transmit(&huart1, (uint8_t *) INIT_START_TEXT, sizeof(INIT_START_TEXT), HAL_MAX_DELAY);
#ifdef ZABBIX_ENABLE
  HAL_GPIO_WritePin(nRst_GPIO_Port, nRst_Pin, GPIO_PIN_RESET);	// Reset W5500
  HAL_GPIO_WritePin(nRst_GPIO_Port, nRst_Pin, GPIO_PIN_SET);
  HAL_GPIO_WritePin(SCSN_GPIO_Port, SCSN_Pin, GPIO_PIN_SET);
  HAL_UART_Transmit(&huart1, (uint8_t *) WAIT_W5500, sizeof(WAIT_W5500), HAL_MAX_DELAY);
  HAL_Delay(2000);
  init_w5500();
  HAL_UART_Transmit(&huart1, (uint8_t *) OK, sizeof(OK), HAL_MAX_DELAY);
  eternetErrorCount = 0;
#else
  HAL_GPIO_WritePin(nRst_GPIO_Port, nRst_Pin, GPIO_PIN_RESET);	// Reset W5500
#endif
#ifdef BME280_ENABLE
	  HAL_UART_Transmit(&huart1, (uint8_t *) WAIT_BME280, sizeof(WAIT_BME280), HAL_MAX_DELAY);
  BME280_Init();
  HAL_UART_Transmit(&huart1, (uint8_t *) OK, sizeof(OK), HAL_MAX_DELAY);
#endif

  rwFlash(0);		// Чтение параметров калибровки из Flash.

  /* Таймер задержки запуска измерения */
  receiversOff
  //C_13 = CALIBRATE_START;
  if (C_1 == 0) {
	  C_1 = CALIBRATE_START;
  }
  if (C_2 == 0) {
	  C_2 = CALIBRATE_START;
  }
  if (C_3 == 0) {
	  C_3 = CALIBRATE_START;
  }
  if (C_4 == 0) {
	  C_4 = CALIBRATE_START;
  }
  TIM3->ARR = C_3; 		// Коррекция для таймера запуска измерения Z13
  /*
   * calibrateMode == 0 -- Нормальный режим
   * calibrateMode > 0 -- Режим калибровки
   */
  calibrateMode = 0;
  test_flag = FALSE;
  Xsum = 0;
  Ysum = 0;
  Vmax = 0;
  firstTime = TRUE;
  currentMode = 0;
  STOP_CAPTURE
  TIM1->ARR = TIM1_PERIOD - 1;
  measCount = 0;
  /*
   *	Очистка массива результатов.
   */
  for (int ii = 0; ii < MEASSURE_COUNT; ii++) {
	  resul_arrayX1[ii] = 0;
	  resul_arrayY1[ii] = 0;
	  resul_arrayX2[ii] = 0;
	  resul_arrayY2[ii] = 0;
  }
  calibrate1 = FALSE;
  calibrate3 = FALSE;
  calibrate2 = FALSE;
  calibrate4 = FALSE;

  HAL_UART_Transmit(&huart1, (uint8_t *) INIT_FINISH_TEXT, sizeof(INIT_FINISH_TEXT), HAL_MAX_DELAY);


  HAL_TIM_Base_Start_IT(&htim3);
  HAL_TIM_Base_Start_IT(&htim4);
  /* USER CODE END 2 */
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

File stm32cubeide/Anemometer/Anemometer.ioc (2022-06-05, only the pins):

Mcu.UserName=STM32F103C8Tx
PB11.Signal=GPIO_Output
PB15.Signal=SPI2_MOSI
PB13.Signal=SPI2_SCK
PD1-OSC_OUT.Signal=RCC_OSC_OUT
PA15.GPIO_Label=TP
PA12.Signal=GPIO_Output
PB6.Signal=USART1_TX
PB2.Signal=GPIO_Output
PB12.GPIO_Label=Eth_CS
PB1.GPIO_Label=Z1Receive
PA10.GPIO_Label=Z3
PB7.Signal=USART1_RX
PA8.Signal=S_TIM1_CH1
PB9.Signal=I2C1_SDA
PB1.Signal=GPIO_Output
PA10.Signal=S_TIM1_CH3
PA15.Signal=GPIO_Output
PB4.Signal=GPIO_Output
PB3.GPIO_Label=Eth_int
PB9.GPIO_Label=TMP117_SDA
PA9.GPIO_Label=Z2
PB11.GPIO_Label=Z4Receive
PA11.GPIO_Label=Z4
PD0-OSC_IN.Signal=RCC_OSC_IN
PA12.GPIO_Label=LED
PA0-WKUP.GPIO_Label=senserInput
PA0-WKUP.Signal=S_TIM2_CH1_ETR
PB8.GPIO_Label=TMP117_SCL
PA8.GPIO_Label=Z1
PB10.GPIO_Label=Z3Receive
PA9.Signal=S_TIM1_CH2
PB10.Signal=GPIO_Output
PB14.Signal=SPI2_MISO
PB4.GPIO_Label=Eth_rst
PB3.Signal=GPIO_Output
PA11.Signal=S_TIM1_CH4
PB2.GPIO_Label=Z2Receive
PB8.Signal=I2C1_SCL
PB12.Signal=GPIO_Output

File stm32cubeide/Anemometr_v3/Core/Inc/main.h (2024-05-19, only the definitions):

#define TRUE 1
#define FALSE 0
#define SPEED_CALIBRATE 46.87f
#define CHANNELS 4
#define PREFETCH 2					/* Количество игнорируемых измерений. Для устранения шума. */
#define CALIBRATE_START 40000		/* Начальное смещение начала измерения */
#define TIM1_PERIOD 800				/* Количество тактов для одного периода ~40kHz */
#define MAX_SPD 40.00f				/* Допустимая максимальная скорость, все, что выше -- игнорируется */
#define COUNT_FRONT 28				/* Количество переходов в одном цикле измерения */
#define MEASSURE_COUNT 100			/* Количество циклов в стандартном измерении */
#define CALIBRATE_MAX_COUNT 1600	/* Диапазон перебора смещения задержки измерения */
#define CALIBRATE_TIMES 5			/* Количество стандартных измерений измерений для точной калибровки */
#define CALIBRATE_ACURACY 1.0f		/* Максимальное отклонение при переборе смещения измерения */
#define AUTO_CALIBRATE				/* Подстройка средней точки диапазона для компенсации температуры и деформации корпуса */
#define FAST_CALIBRATE 50			/* Порог для ускоренной калибровки */
#define FAST_CALIBRATE_STEP 30		/* Шаг быстрой калибровки */
#define Z1Receive 1
#define Z2Receive 2
#define Z3Receive 3
#define Z4Receive 4
#define START_CAPTURE HAL_TIM_IC_Start_IT(&htim2, TIM_CHANNEL_1); HAL_TIM_IC_Start_IT(&htim2, TIM_CHANNEL_2);
#define STOP_CAPTURE HAL_TIM_IC_Stop_IT(&htim2, TIM_CHANNEL_1); HAL_TIM_IC_Stop_IT(&htim2, TIM_CHANNEL_2);
#define receiversOff GPIOB->ODR |= (1 << Z1Receive) | (1 << Z2Receive) | (1 << Z3Receive) | (1 << Z4Receive);
#define setZ1receive GPIOB->ODR &= ~((1 << Z1Receive)); GPIOA->CRH = (GPIOA->CRH & ~(GPIO_CRH_CNF8 | GPIO_CRH_MODE8)) | GPIO_CRH_CNF8_0;
#define setZ2receive GPIOB->ODR &= ~((1 << Z2Receive)); GPIOA->CRH = (GPIOA->CRH & ~(GPIO_CRH_CNF9 | GPIO_CRH_MODE9)) | GPIO_CRH_CNF9_0;
#define setZ3receive GPIOB->ODR &= ~((1 << Z3Receive)); GPIOA->CRH = (GPIOA->CRH & ~(GPIO_CRH_CNF10 | GPIO_CRH_MODE10)) | GPIO_CRH_CNF10_0;
#define setZ4receive GPIOB->ODR &= ~((1 << Z4Receive)); GPIOA->CRH = (GPIOA->CRH & ~(GPIO_CRH_CNF11 | GPIO_CRH_MODE11)) | GPIO_CRH_CNF11_0;
#define LED_PULSE HAL_GPIO_WritePin(LED_GPIO_Port, LED_Pin, GPIO_PIN_SET); HAL_GPIO_WritePin(LED_GPIO_Port, LED_Pin, GPIO_PIN_RESET);
#define TP_PULSE HAL_GPIO_WritePin(TP_GPIO_Port, TP_Pin, GPIO_PIN_SET); HAL_GPIO_WritePin(TP_GPIO_Port, TP_Pin, GPIO_PIN_RESET);
#define TP_Pin GPIO_PIN_2
#define TP_GPIO_Port GPIOA
#define LED_Pin GPIO_PIN_7
#define LED_GPIO_Port GPIOA
#define Z1_Pin GPIO_PIN_1
#define Z1_GPIO_Port GPIOB
#define Z2_Pin GPIO_PIN_2
#define Z2_GPIO_Port GPIOB
#define SCSN_Pin GPIO_PIN_12
#define SCSN_GPIO_Port GPIOB
#define OUTZ1_Pin GPIO_PIN_8
#define OUTZ1_GPIO_Port GPIOA
#define OUTZ2_Pin GPIO_PIN_9
#define OUTZ2_GPIO_Port GPIOA
#define OUTZ3_Pin GPIO_PIN_10
#define OUTZ3_GPIO_Port GPIOA
#define OUTZ4_Pin GPIO_PIN_11
#define OUTZ4_GPIO_Port GPIOA
#define nRst_Pin GPIO_PIN_12
#define nRst_GPIO_Port GPIOA
#define Z3_Pin GPIO_PIN_3
#define Z3_GPIO_Port GPIOB
#define Z4_Pin GPIO_PIN_4
#define Z4_GPIO_Port GPIOB
#define INIT_FINISH_TEXT "\n\rFinish init...\n\r"
#define INIT_START_TEXT "\n\rStart init...\n\r"
#define DHCP_ERROR_ASSIGN "\r\nIP was not assigned :(\r\n"
#define CALIBRATE_TEXT "\r\nStart callibrate \r\n"
#define CALIBRATE_ERROR_RANGE "\r\nCalibrate ERROR.\r\nDelta out of range.\r\n"
#define CALIBRATE_ERROR_TOUT "\r\nCalibrate ERROR.\r\nTime out\r\n"
#define TEST_TEXT "\r\nStart test.\r\n"
#define TEST_TERMINATE "\r\nTerminate test or calibrate.\r\n"
#define WAIT_BME280 "Wait BME280."
#define OK "Ok.\r\n"
#define WAIT_W5500  "Wait W5500."
#define MAX_ETH_ERROR	100
#define DHCP_SOCKET     0
#define DNS_SOCKET      1
#define TCP_SOCKET		2
#define DHCP_TRY_CNT	1000
#define ZABBIX_ENABLE					/* Включает сетевой интерфейс и инициирует запись данных в zabbix */
#define ZABBIX_RAW_DATA					/* Сохранение исходных значений, для температурной калибровки. */
#define ZABBIXAGHOST	"Anemometer"  // Default hostname.
#define ZABBIXPORT		10051
#define ZABBIXMAXLEN	128
#define MAC_ADDRESS		0x00, 0x11, 0x22, 0x35, 0x44, 0xEA

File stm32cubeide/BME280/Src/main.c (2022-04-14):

/**
  ******************************************************************************
  * @file           : main.c
  * @brief          : Main program body
  ******************************************************************************
  ** This notice applies to any and all portions of this file
  * that are not between comment pairs USER CODE BEGIN and
  * USER CODE END. Other portions of this file, whether 
  * inserted by the user or by software development tools
  * are owned by their respective copyright owners.
  *
  * COPYRIGHT(c) 2018 STMicroelectronics
  *
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
  ******************************************************************************
  */
/* Includes ------------------------------------------------------------------*/
#include "main.h"
#include "stm32f4xx_hal.h"

/* USER CODE BEGIN Includes */
#include <string.h>
#include "BME280.h"
#include "lcd.h"
/* USER CODE END Includes */

I2C_HandleTypeDef hi2c1;
I2C_HandleTypeDef hi2c3;

UART_HandleTypeDef huart2;

/* USER CODE BEGIN PV */
char str1[100];
/* USER CODE END PV */

void SystemClock_Config(void);
static void MX_GPIO_Init(void);
static void MX_USART2_UART_Init(void);
static void MX_I2C1_Init(void);
static void MX_I2C3_Init(void);

/* USER CODE BEGIN PFP */

/* USER CODE END PFP */

/**
  * @brief  The application entry point.
  *
  * @retval None
  */
int main(void)
{
  /* USER CODE BEGIN 1 */
	float tf = 0.0f, pf = 0.0f, af = 0.0f, hf = 0.0f;
  /* USER CODE END 1 */

  /* MCU Configuration----------------------------------------------------------*/

  /* Reset of all peripherals, Initializes the Flash interface and the Systick. */
  HAL_Init();

  /* Configure the system clock */
  SystemClock_Config();

  /* Initialize all configured peripherals */
  MX_GPIO_Init();
  MX_USART2_UART_Init();
  MX_I2C1_Init();
  MX_I2C3_Init();
  /* USER CODE BEGIN 2 */
	LCD_ini();
	BME280_Init();
  /* USER CODE END 2 */

  /* Infinite loop */
  /* USER CODE BEGIN WHILE */
  while (1)
  {

  /* USER CODE END WHILE */

  /* USER CODE BEGIN 3 */
		tf = BME280_ReadTemperature();
		sprintf(str1, "Temperature: %.3f *C\r\n", tf);
		HAL_UART_Transmit(&huart2,(uint8_t*)str1,strlen(str1),0x1000);
		LCD_SetPos(0, 0);
		sprintf(str1, "%11.3f *C", tf);
		LCD_String(str1);
		pf = BME280_ReadPressure();
		sprintf(str1, "Pressure: %.3f Pa; %.3f hPa; %.3f mmHg\r\n", pf, pf/1000.0f, pf * 0.000750061683f);
		HAL_UART_Transmit(&huart2,(uint8_t*)str1,strlen(str1),0x1000);
		LCD_SetPos(0, 1);
		sprintf(str1, "%11.3f hPa", pf/1000.0f);
		LCD_String(str1);
		LCD_SetPos(0, 2);
		sprintf(str1, "%11.3f mmHg", pf * 0.000750061683f);
		LCD_String(str1);
		af = BME280_ReadAltitude(SEALEVELPRESSURE_PA);
		sprintf(str1, "Altitude: %.3f m\r\n", af);
		HAL_UART_Transmit(&huart2,(uint8_t*)str1,strlen(str1),0x1000);
		hf = BME280_ReadHumidity();
		sprintf(str1, "Humidity: %.3f %%\r\n", hf);
		HAL_UART_Transmit(&huart2,(uint8_t*)str1,strlen(str1),0x1000);
		LCD_SetPos(0, 3);
		sprintf(str1, "%7.3f %% %4.1f m", hf, af);
		LCD_String(str1);
		HAL_Delay(1000);
  }
  /* USER CODE END 3 */

}

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


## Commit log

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2022-01-16 новый файл: Documents/AnalogMux.ods новый файл: Documents/Makefile новый файл: Documents/Quotation-20211224.pdf новый файл: Documents/RS-CFSFX-N01-3 Ultrasonic wind speed and direction 485.pdf новый 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
    [AnalogMux.ods, Anemometr.sch]
2022-01-16 новый файл: FreeCAD/base-3.FCStd новый файл: FreeCAD/holder-3.fcstd изменено: stm32cubeide/Anemometer/Core/Src/stm32f1xx_it.c изменено: stm32cubeide/Anemometer/Release/Anemometer.bin изменено: stm32c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
    [base-3.FCStd, holder-3.fcstd]
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2022-01-19 изменено: kicad/Anemometr/Anemometr-cache.lib изменено: kicad/Anemometr/Anemometr.kicad_pcb изменено: kicad/Anemometr/Anemometr.kicad_pcb-bak изменено: kicad/Anemometr/Anemometr.sch изменено: kicad/A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
    [Anemometr.kicad_pcb, Anemometr.sch]
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2022-01-20 изменено: kicad/Anemometr/Anemometr-cache.lib изменено: kicad/Anemometr/Anemometr-rescue.lib изменено: kicad/Anemometr/Anemometr.kicad_pcb изменено: kicad/Anemometr/Anemometr.kicad_pcb-bak изменено: 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
    [Anemometr.kicad_pcb, Anemometr.sch]
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2022-01-21 изменено: kicad/Anemometr/Anemometr.sch изменено: kicad/Anemometr/Anemometr.sch-bak изменено: stm32cubeide/Anemometer/Anemometer.ioc изменено: stm32cubeide/Anemometer/Core/Inc/main.h изменено: stm32c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
    [Anemometr.sch]
2022-01-22 изменено: kicad/Anemometr/Anemometr.sch изменено: kicad/Anemometr/Anemometr.sch-bak изменено: stm32cubeide/Anemometer/Anemometer.ioc изменено: stm32cubeide/Anemometer/Core/Inc/main.h изменено: stm32c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
    [Anemometr.sch]
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2022-01-23 изменено: kicad/Anemometr/Anemometr.sch изменено: kicad/Anemometr/Anemometr.sch-bak изменено: stm32cubeide/Anemometer/Anemometer.ioc изменено: stm32cubeide/Anemometer/Core/Inc/main.h изменено: stm32c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
    [Anemometr.sch]
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2022-01-24 удалено: ../../Documents/AnalogMux.ods удалено: ../../Documents/Ethernet_W5500.odt удалено: ../../Documents/H1102N.pdf удалено: ../../Documents/Makefile удалено: ../../Documents/Quotation-20211224.pd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
    [AnalogMux.ods]
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2022-02-01 новый файл: kicad/Anemometr/Documents/AnalogMux.ods новый файл: kicad/Anemometr/Documents/Ethernet_W5500.odt новый файл: kicad/Anemometr/Documents/H1102N.pdf новый файл: kicad/Anemometr/Documents/SD4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
    [AnalogMux.ods]
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2022-02-02 новый файл: Documents/boardA.png новый файл: Documents/boardB.png изменено: Documents/circuit.png изменено: kicad/Anemometr/Anemometr.kicad_pcb изменено: kicad/Anemometr/Anemometr.kicad_pcb-bak измен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
    [Anemometr.kicad_pcb, Anemometr.sch]
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2022-02-17 изменено: kicad/Anemometr/Anemometr.kicad_pcb изменено: kicad/Anemometr/Anemometr.kicad_pcb-bak изменено: kicad/Anemometr/Anemometr.sch изменено: kicad/Anemometr/Anemometr.sch-bak изменено: kicad/Ane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
    [Anemometr.kicad_pcb, Anemometr.sch]
2022-02-18 новый файл: FreeCAD/base-4.FCStd новый файл: FreeCAD/base-4.stl новый файл: FreeCAD/cover-4.fcstd новый файл: FreeCAD/cover-4.stl изменено: stm32cubeide/Anemometer/Anemometer.ioc изменено: stm32cubei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
    [base-4.FCStd, base-4.stl, cover-4.fcstd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]
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2022-02-27 изменено: kicad/Anemometr/Anemometr.kicad_pcb изменено: kicad/Anemometr/Anemometr.kicad_pcb-bak изменено: kicad/Anemometr/Anemometr.sch изменено: kicad/Anemometr/Anemometr.sch-bak изменено: kicad/Ane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
    [Anemometr.kicad_pcb, Anemometr.sch]
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2022-02-28 изменено: kicad/Anemometr/Anemometr-cache.lib изменено: kicad/Anemometr/Anemometr-rescue.lib изменено: kicad/Anemometr/Anemometr.kicad_pcb изменено: kicad/Anemometr/Anemometr.kicad_pcb-bak изменено: 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
    [Anemometr.kicad_pcb, Anemometr.sch]
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2022-03-05 изменено: FreeCAD/base-4.FCStd изменено: FreeCAD/base-4.stl изменено: FreeCAD/cover-4.fcstd изменено: FreeCAD/cover-4.stl изменено: FreeCAD/holder-3.fcstd изменено: kicad/Anemometr/Anemometr.kicad_pc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
    [Anemometr.kicad_pcb, Anemometr.sch, base-4.FCStd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]
2022-03-07 изменено: kicad/Anemometr/Anemometr.kicad_pcb изменено: kicad/Anemometr/Anemometr.kicad_pcb-bak изменено: kicad/Anemometr/Anemometr.sch изменено: kicad/Anemometr/Anemometr.sch-bak изменено: kicad/Ane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
    [Anemometr.kicad_pcb, Anemometr.sch]
2022-03-08 изменено: kicad/Anemometr/Anemometr.sch изменено: kicad/Anemometr/Anemometr.sch-bak изменено: stm32cubeide/Anemometer/.mxproject изменено: stm32cubeide/Anemometer/Anemometer.ioc изменено: stm32cubeid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
    [Anemometr.sch]
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2022-03-13 изменено: kicad/Anemometr/Anemometr.kicad_pcb изменено: kicad/Anemometr/Anemometr.kicad_pcb-bak изменено: kicad/Anemometr/Anemometr.sch изменено: kicad/Anemometr/Anemometr.sch-bak изменено: stm32cube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
    [Anemometr.kicad_pcb, Anemometr.sch]
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2022-03-15 изменено: Documents/circuit.png изменено: kicad/Anemometr/Anemometr-cache.lib изменено: kicad/Anemometr/Anemometr.kicad_pcb изменено: kicad/Anemometr/Anemometr.kicad_pcb-bak изменено: kicad/Anemometr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
    [Anemometr.kicad_pcb, Anemometr.sch]
2022-03-20 изменено: kicad/Anemometr/Anemometr-cache.lib изменено: kicad/Anemometr/Anemometr-rescue.lib изменено: kicad/Anemometr/Anemometr.kicad_pcb изменено: kicad/Anemometr/Anemometr.kicad_pcb-bak изменено: 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
    [Anemometr.kicad_pcb, Anemometr.sch]
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2023-02-13 новый файл: Documents/jitter-01.png новый файл: Documents/jitter-02.png новый файл: Documents/jitter-03.png
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2023-02-14 новый файл: Documents/80.png новый файл: Documents/88.png удалено: Documents/jitter-01.png изменено: stm32cubeide/Anemometr_v3/Anemometr_3.ioc изменено: stm32cubeide/Anemometr_v3/Core/Inc/main.h изме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
    [Anemometr_3.ioc, main.c, main.h]
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2023-03-18 новый файл: ../Documents/63mm-Crystall_200khz.png новый файл: ../Documents/Crystall-40kHz.png новый файл: ../Documents/Crystall_200khz.png новый файл: ../Documents/Jitter-Crystall_200khz.png изменено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
    [main.c, main.h]
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

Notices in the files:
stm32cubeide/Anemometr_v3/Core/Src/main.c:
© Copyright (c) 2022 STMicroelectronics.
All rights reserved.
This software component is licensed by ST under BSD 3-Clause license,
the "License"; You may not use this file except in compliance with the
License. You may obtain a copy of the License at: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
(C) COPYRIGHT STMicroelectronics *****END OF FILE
